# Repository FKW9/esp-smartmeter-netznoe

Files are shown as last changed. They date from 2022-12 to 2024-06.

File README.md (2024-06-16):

# ESP32 Smartmeter Logger für P1 Kundenschnittstelle
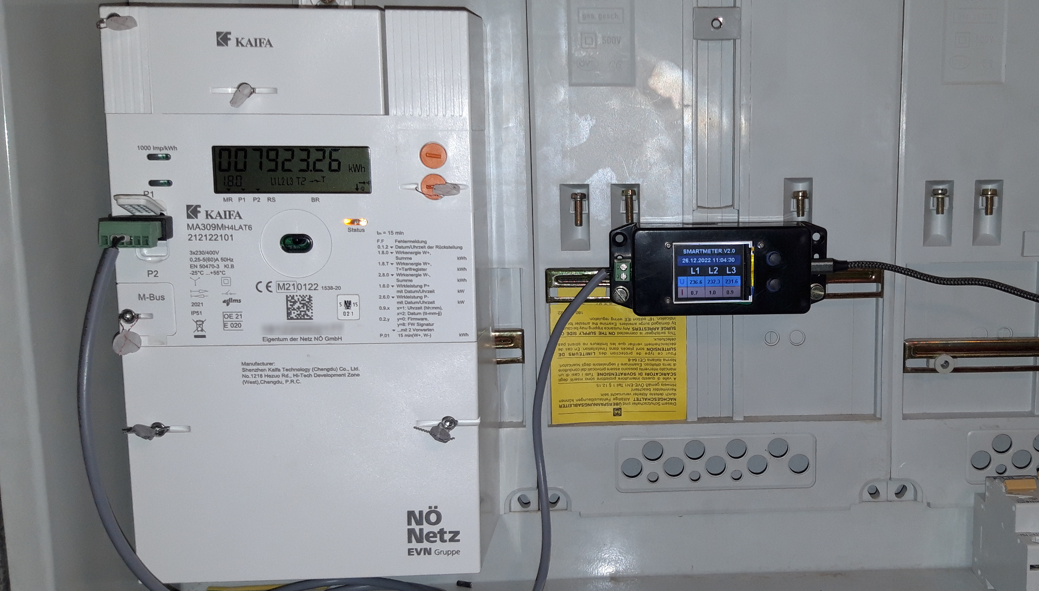
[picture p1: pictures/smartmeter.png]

Musste mich gegen ein DIN-Hutschienengehäuse entscheiden, da in meinem Schaltschrank kein Platz mehr war...

## Quellen
 - DLMS Entschlüsselung: [esphome-dlms-meter](https://github.com/DomiStyle/esphome-dlms-meter)
 - Datenlogger: [ESPLogger](https://github.com/fabianoriccardi/ESPLogger)
 - Fileserver: [esp32-asyncwebserver-fileupload](https://github.com/smford/esp32-asyncwebserver-fileupload-example)
 - weitere siehe [platformio.ini](/platformio.ini)

## Unterstützte Smartmeter
- Kaifa MA309M
- Sagecom T210-D

## Unterstützte (bekannte) Netzbetreiber
- Netz Niederösterreich
- VKW (in Entwicklung, siehe Branch [vkw-test](https://github.com/FKW9/esp-smartmeter-netznoe/tree/vkw-test) und [Issue #10](https://github.com/FKW9/esp-smartmeter-netznoe/issues/10)

## Features
- Lest alle verfügbaren OBIS Daten von der Kundenschnittstelle P1 aus
- Speichert alle Daten auf einer SD-Karte im CSV Format ab
- Daten können über einen Webserver heruntergeladen werden
- Daten können an eine [Graphite-Datenbank](https://graphiteapp.org/) gesendet werden
- On-board [Feuchte und Temperatursensor](https://github.com/epluse/HTE501_i2c_arduino)
- TFT Display auf dem aktuelle Werte zu sehen sind, welches sich automatisch nach 2 Minuten inaktivität ausschaltet.
- [WiFi Manager](https://github.com/tzapu/WiFiManager) zum bequemen Aufsetzen

## Allgemeines
Zunächst muss der Entschlüsselungscode angefordert werden. Für Niederösterreich E-Mail an: [smartmeter@netz-noe.at](mailto:smartmeter@netz-noe.at)

Information zur Kundenschnittstelle (netz-nö) sind hier zu finden: [www.netz-noe.at/SmartMeter_Kundenschnittstelle_lektoriert.aspx](https://www.netz-noe.at/Download-(1)/Smart-Meter/218_9_SmartMeter_Kundenschnittstelle_lektoriert_14.aspx).
## Bekannte Probleme
Leistungsfaktor ist teils unglaubwürdig, siehe dazu [Issue #7](https://github.com/FKW9/esp-smartmeter-netznoe/issues/7)

## Software Installation
Das Projekt wurde in PlatformIO entwickelt. Um es zu kompilieren, bitte Einstellungen in [**```platformio.ini```**](platformio.ini) übernehmen.

[**```key.h```**](key.h):
- ```KEY[]```: Hier **muss** der Entschlüsselungs-Code eingetragen werden

[**```config.h```**](config.h):
- ```SD_CARD_LOGGING```: Speichern auf SD-Karte bzw. den Fileserver (de)aktivieren
- ```USE_GRAPHITE```: Daten an Graphite senden (de)aktivieren

### TFT Display Setup
siehe [**```lib/display/README.md```**](lib/display/README.md)

### Optionale Einstellungen
[**```lib/fileserver/fileserver.h```**](lib/fileserver/fileserver.h):
- ```default_httppassword = "admin"```: Fileserver Login Username
- ```default_httppassword = "smartmeter"```: Fileserver Login Passwort

### Test Setup
In [platformio.ini](/platformio.ini) kann das Flag ```TEST_SETUP``` verwendet werden, um ohne Smartmeter die Funktionalität zu überprüfen. Dazu muss **mein** Schlüssel in [key.h](/key.h) verwendet werden.

## Flowchart
```mermaid
flowchart LR
   Smartmeter -- M-Bus --> a[M-Bus UART Konverter] -- UART --> ESP32
   ESP32 --> Decrypting
   subgraph ESP32
   Decrypting -- save -->b[SD-Karte]
   c[SD-Karte] -- serve --> Webserver
   Decrypting-- push --> d[Graphite Server]
   end
   ESP32-- display -->e[TFT Display]
```

## Hardware
Für eine simplere Hardware Version siehe [Release V0.1](https://github.com/FKW9/esp-smartmeter-netznoe/tree/V0.1).

Als Folge meiner ersten Version wurde hier eine eigene PCB mit mehr Features entworfen.
Diese beinhaltet folgende Kern-Komponenten:
- ESP32-S Modul (mit IPEX Konnektor für Antenne, falls schlechter Empfang)
- CP2102 USB-UART Konverter
- Micro SD-Karten Slot
- 1,77 Zoll TFT Display (160x128px)
- TSS721ADR M-Bus zu UART Konverter (Spende vom [M-Bus Slave Click](https://www.mikroe.com/m-bus-slave-click) Board😉)
- Zweipolige Steckklemme für M-Bus Anschluss (TODO: besser wäre direkt eine RJ12 Buchse!)
- Micro USB für Versorgung bzw. Debugging
- Zwei Taster für die Menüführung

Schaltplan, BOM, Anmerkungen, Zukünftige Verbesserungen der PCB usw. befinden sich im Ordner [hardware](/hardware/).

Für einen "simplen" Aufbau wird folgendes benötigt:
- [M-Bus Slave Click](https://www.mikroe.com/m-bus-slave-click) Board (oder Kompatible)
- ESP32 Development Board, vorzugsweise mit SD-Karten Slot
- RJ12 Kabel bzw. (optional) RJ12 Adapter ([Amazon](https://www.amazon.de/ASHATA-Schraubklemmen-Terminalblock-Schraubanschluss-Konverter-default/dp/B07N3WY7R5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), [AliExpress](https://de.aliexpress.com/item/32870211601.html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)) (Anmerkung: Die Gummiisolierung muss etwas getrimmt werden, damit er passt)
- *(optional)* Micro SD-Karten Modul
- *(optional)* 1,77 Zoll TFT Display ([Amazon](https://www.amazon.de/AZDelivery-TFT-Display-128x160-Pixeln-gratis/dp/B078JBBPXK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), [AliExpress](https://de.aliexpress.com/item/32812455774.html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)) (Anmerkung: Ist derzeit noch voll im Programm integriert und kann nicht einfach "auskommentiert" werden)

### Verbindungen zwischen ESP und M-Bus:
| ESP32-S Modul | | M-Bus Slave Board | RJ12 | Anmerkung |
|---|---|---|---|---|
| 3.3V  | | 3V3 | | Versorgung |
| GND | | GND | | Masse |
| RXD 2 | GPIO16 | TX | | Empfangene Daten vom M-Bus |
| TXD 2 | GPIO17 | RX | | Optional, da wir keine Daten senden |
| | | MBUS1 | 3 | M-Bus Ausgang, Polarität egal |
| | | MBUS2 | 4 | M-Bus Ausgang, Polarität egal |

### Verbindungen zwischen ESP und TFT Display:
| ESP32-S Modul | | TFT Display | Anmerkung |
|---|---|---|---|
| 3.3V  | | VCC | Versorgung |
| GND | | GND | Masse |
| SCK | GPIO18 | SCK | |
| MOSI  | GPIO23 | SDA | |
| MISO  | GPIO19 | RES | |
| | GPIO25 | RS | |
| SS | GPIO5  | CS | |
| | GPIO26 | LEDA | Display an/aus (Hintergrundbeleuchtung) |

### Verbindungen zwischen ESP und TFT Display:
**Achtung:** Ob ein SPI Micro SD-Karten Modul kompatibel mit dem TFT Display ist, weiß ich nicht. Ich verwende die SD-Karte im 4-Bit SD Bus Mode, welcher folgend aufgelistet ist.
| ESP32-S Modul  | SD-Karte | | Anmerkung |
|---|---|---|---|
| 3.3V | VDD | | Versorgung |
| GND | VSS | | Masse |
| GPIO2  | SD_DATA0 | DAT0 | |
| GPIO4  | SD_DATA1 | DAT1 | |
| GPIO12 | SD_DATA2 | DAT2 | |
| GPIO13 | SD_DATA3 | CD/DAT3 | |
| GPIO15 | SD_CMD | CMD | |
| GPIO14 | SD_CLK | CLK | |
| GPIO27 | SD_CD | CD | Card detect. Erkennt, ob SD-Karte physisch vorhanden ist (Schließer). |
---
## Showcase

### **Fileserver**
Für jeden Monat wird eine Datei erstellt. Ein Monat hat ca. 60MB und dauert somit ungefähr 5 Minuten zum Herunterladen.
Als Übersicht wird oben der SD-Karten Status (Freier Speicher, usw.) angezeigt.
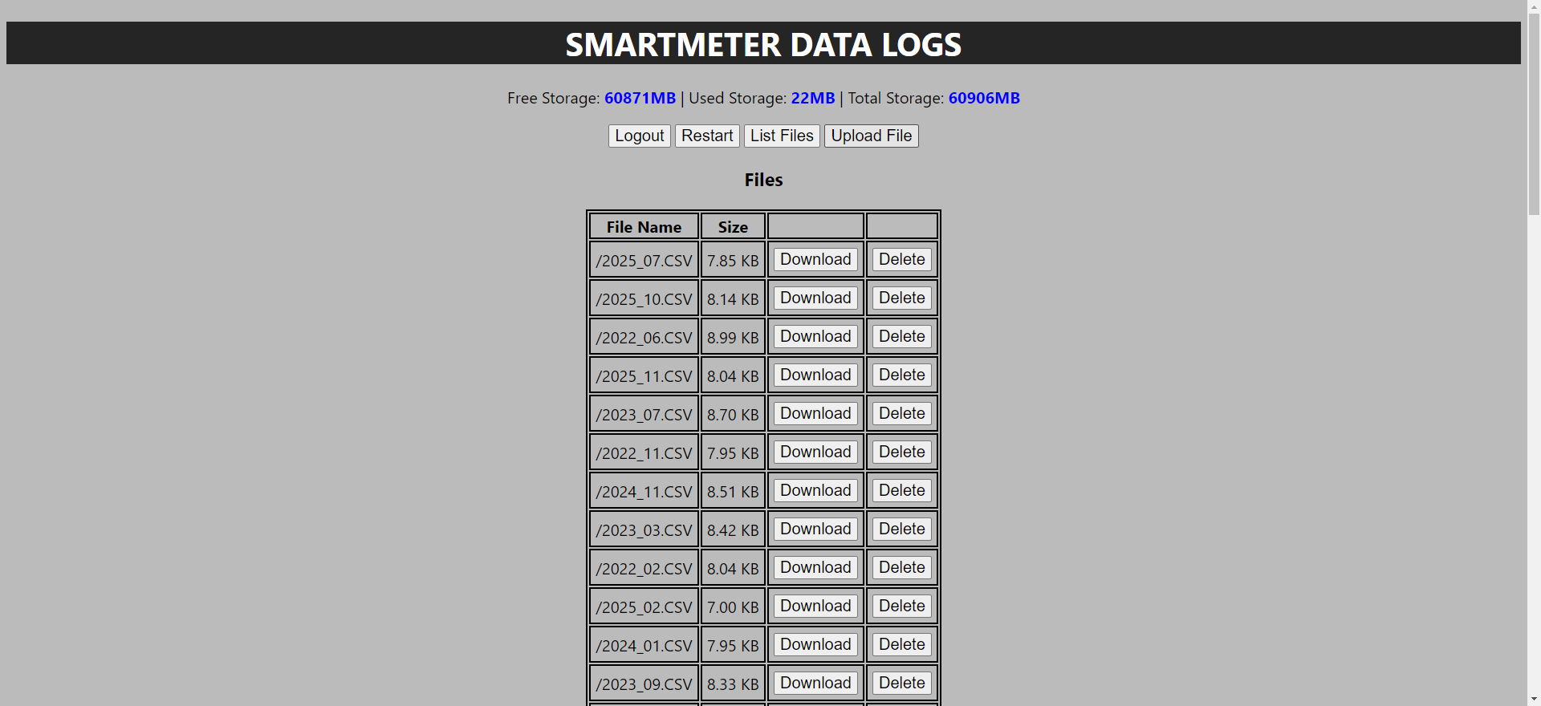
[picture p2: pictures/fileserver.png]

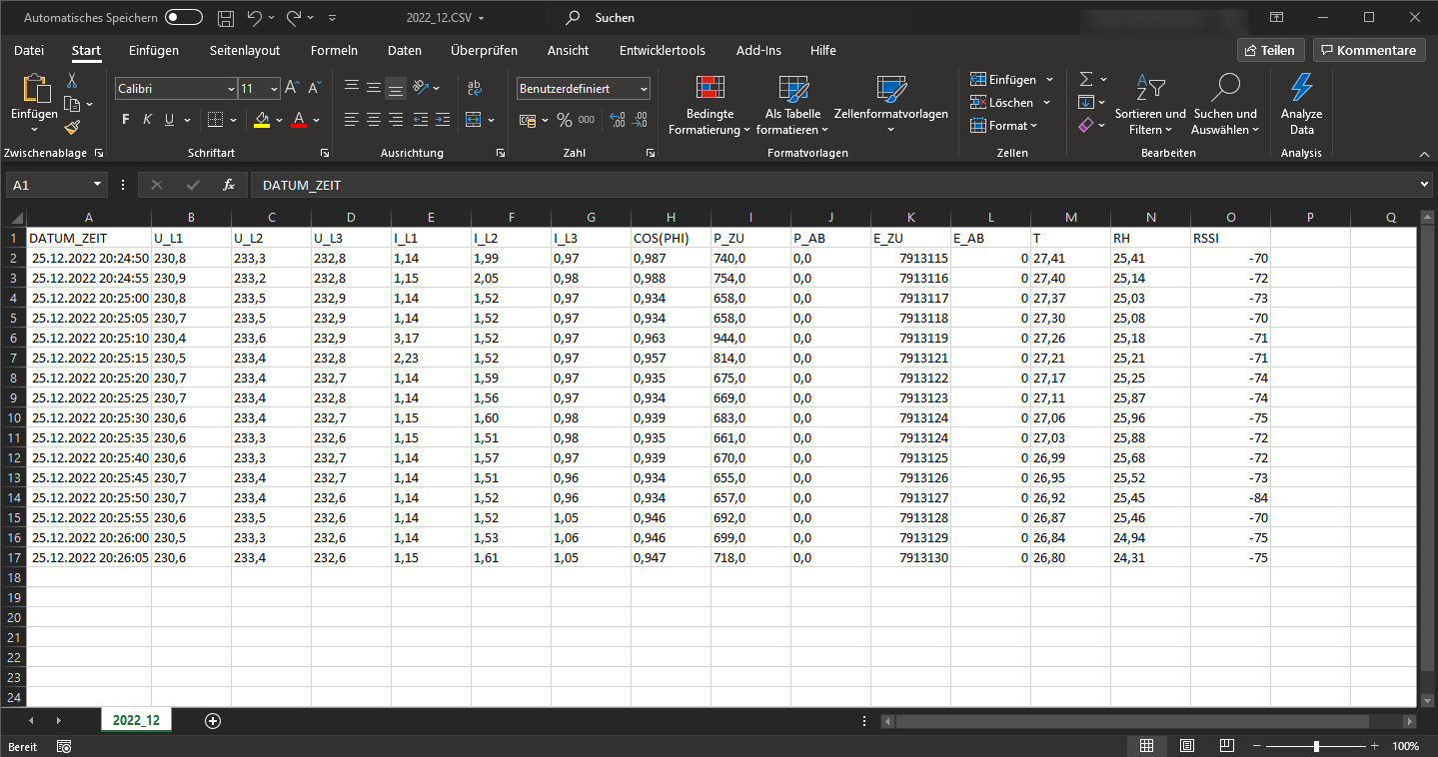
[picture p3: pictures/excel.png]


### **Visualisierung**
Zur Visualisierung wird Grafana (und Graphite) verwendet. Beide Programme laufen auf einem NAS (Synology DS218).
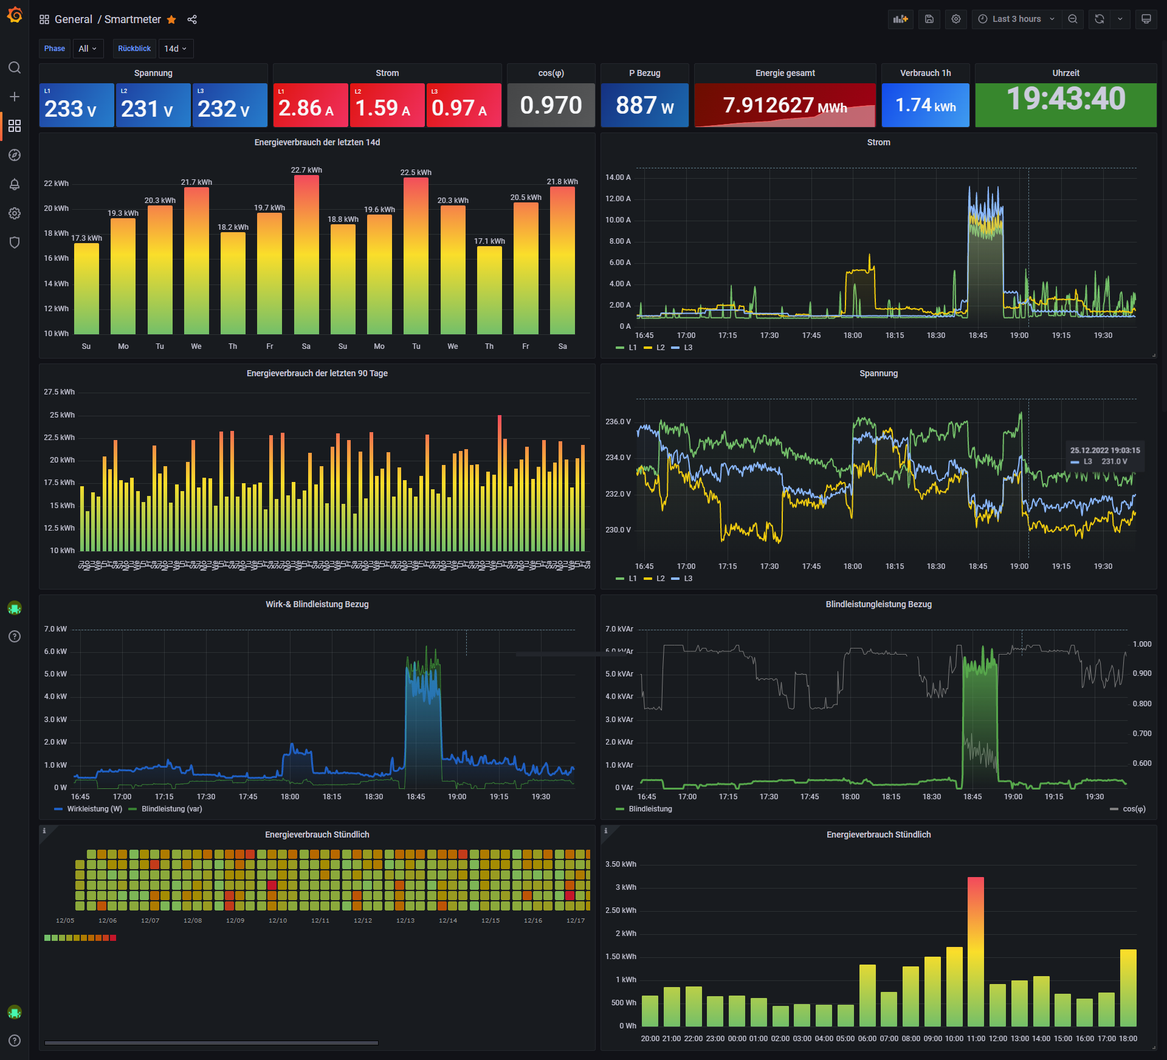
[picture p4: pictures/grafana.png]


### **TFT Display**
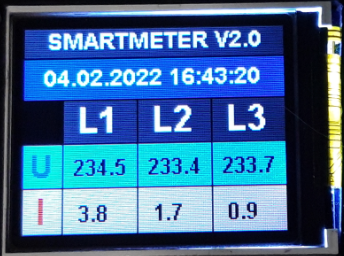
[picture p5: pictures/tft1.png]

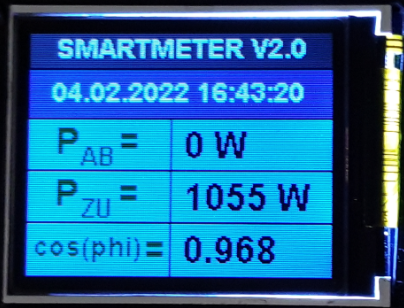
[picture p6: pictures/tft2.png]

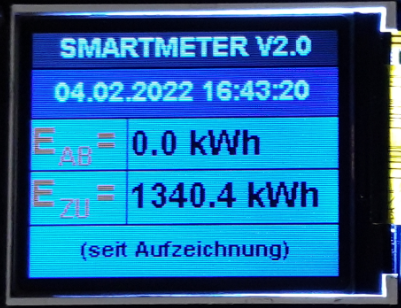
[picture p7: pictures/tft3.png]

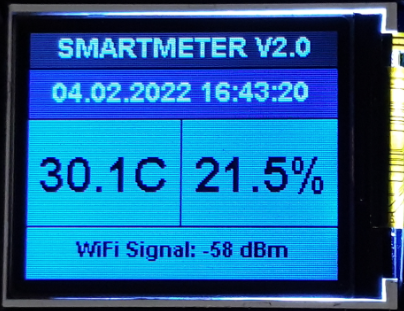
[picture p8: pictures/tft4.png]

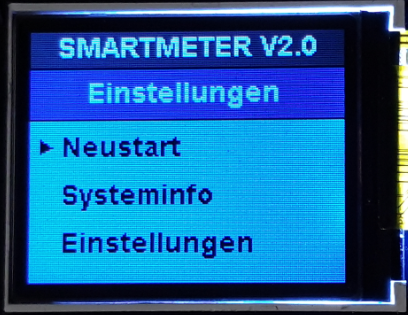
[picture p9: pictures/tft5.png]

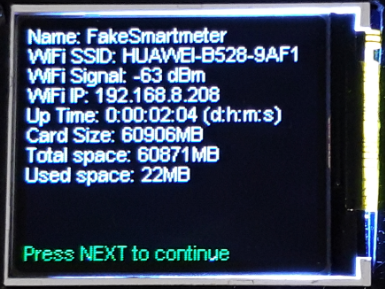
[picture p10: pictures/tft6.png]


### **PCB**
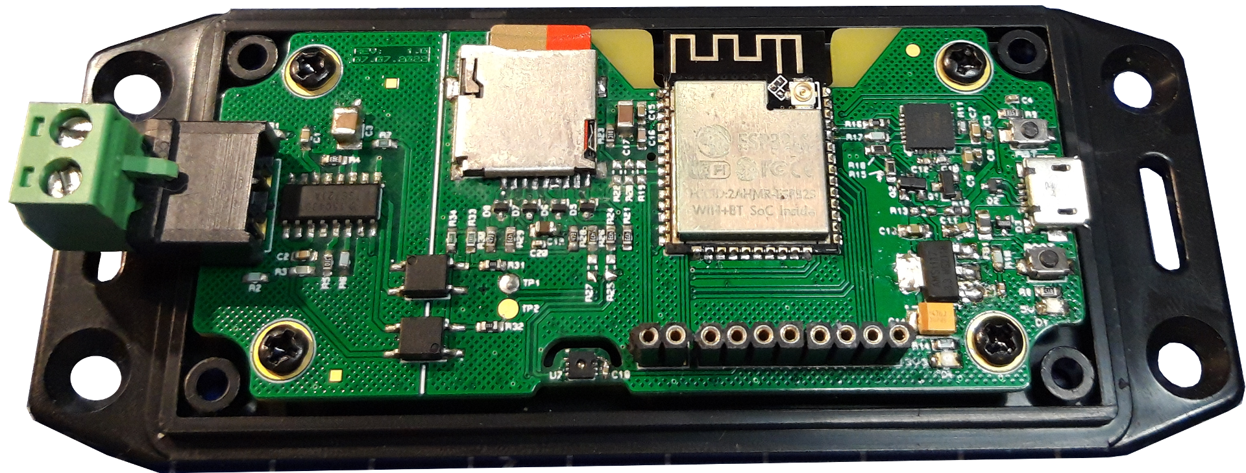
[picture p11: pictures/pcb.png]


## Zukünftiges
Es gibt noch viele Ideen für weitere Entwicklungen, siehe dazu:
- Hardware: [TODO's](/hardware/TODO.md)
- Software: [TODO's](/TODO.md)

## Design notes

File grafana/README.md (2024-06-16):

# Grafana Dashboard

Damit man im Diagramm "Energieverbrauch er letzten 7 Tage" die Wochentage sieht, musste etwas an der Grafana config umgestellt werden. Siehe mein Forum-Beitrag: [https://community.grafana.com/t/default-datetime-formatting-to-weekday-possible/60702](https://community.grafana.com/t/default-datetime-formatting-to-weekday-possible/60702).

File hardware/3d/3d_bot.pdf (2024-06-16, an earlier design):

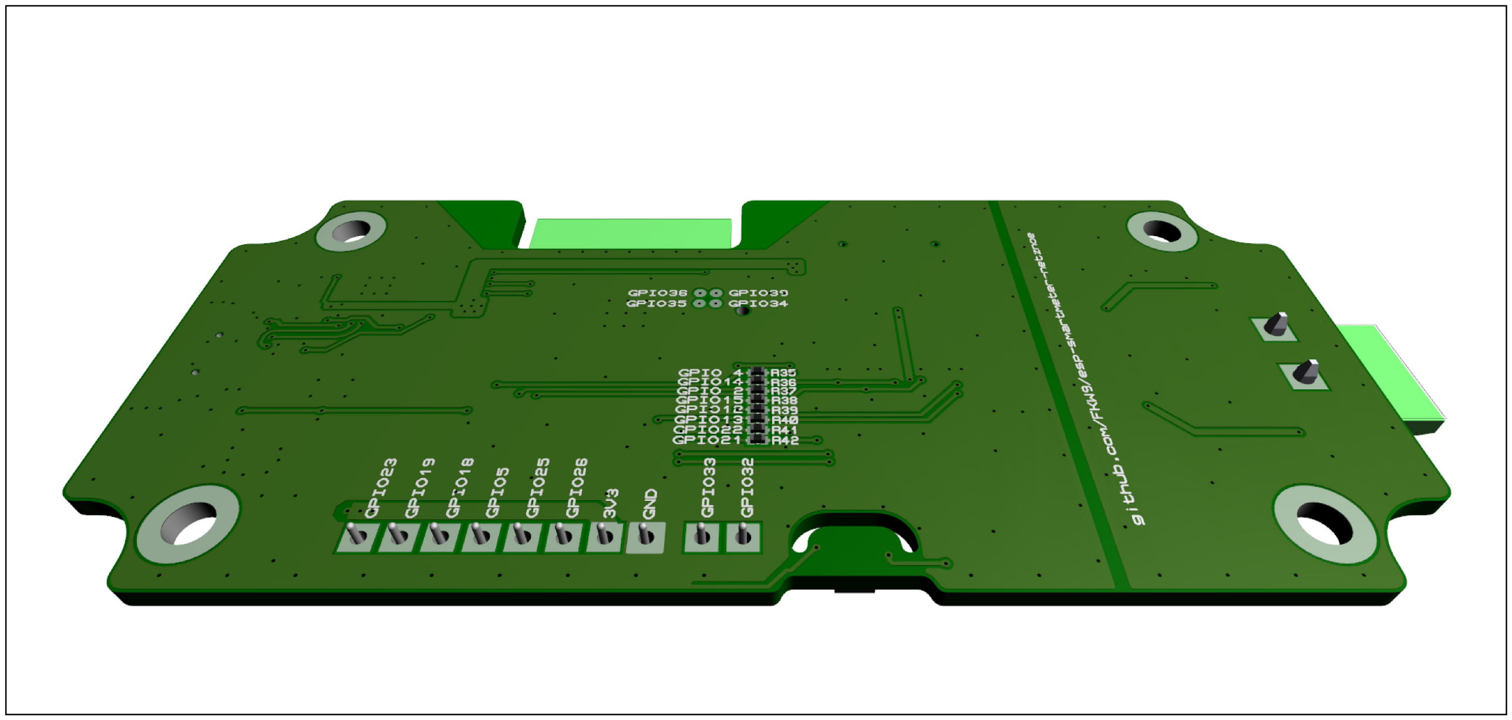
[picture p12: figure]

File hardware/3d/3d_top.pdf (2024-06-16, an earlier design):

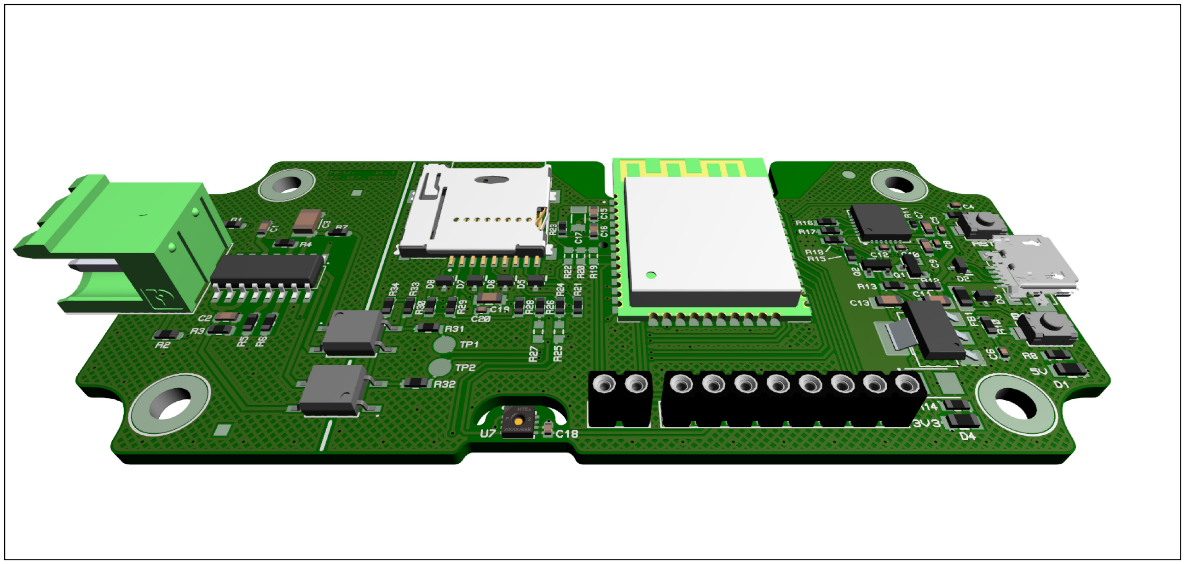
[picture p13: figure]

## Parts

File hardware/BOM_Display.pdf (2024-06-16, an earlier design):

## Bill Of Materials for ESP Smartmeter Logger

Design Title | ESP Smartmeter Logger
Author | FW
Document Number | 0.1
Revision | 1.0
Assembly Variant | STANDARD
Board | Display
Design Created | Sonntag, 12. Juni 2022
Design Last Modified Donnerstag, 16. März 2023

### Total Parts In Design 18

4 Capacitors
Quantity | References | Value | PCB Package | Unit Cost
1 | C1 | 10uF | 1206_CAP | €0,025
1 | C2 | 0.1uF | 0603_CAP | €0,025
2 | C3-C4 | 1uF | 0603_CAP | €0,025
Sub-totals: | | | | €0,100
8 Resistors
Quantity | References | Value | PCB Package | Unit Cost
6 | R1-R6 | 0 | 0603_RES | €0,000
2 | R7-R8 | 10k | 0603_RES | €0,010
Sub-totals: | | | | €0,020
1 Integrated Circuits
Quantity | References | Value | PCB Package | Unit Cost
1 | U1 | TFTDISPLAY | TFT1.77INCH | €3,000
Sub-totals: | | | | €3,000
2 Connectors
Quantity | References | Value | PCB Package | Unit Cost
1 | J1 | CONN-SIL8 | CONN-SIL8 | €0,100
1 | J2 | CONN-SIL2 | CONN-SIL2 | €0,100
Sub-totals: | | | | €0,200
2 Switches
Quantity | References | Value | PCB Package | Unit Cost
1 | SW1 | BUTTON1 | MULTIMEC_3CTH9_10.4 | €1,000
1 | SW2 | BUTTON2 | MULTIMEC_3CTH9_10.4 | €1,000
Sub-totals: | | | | €2,000
1 Additional Cost
Quantity | References | Value | PCB Package | Unit Cost
1 | CT1 | PCB | NULL | €1,000
Sub-totals: | | | | €1,000
Totals: | | | | €6,320

Donnerstag, 16. März 2023 19:24:50

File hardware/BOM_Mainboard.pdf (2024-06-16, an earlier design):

## Bill Of Materials for ESP Smartmeter Logger

Design Title | ESP Smartmeter Logger
Author | FW
Document Number | 0.1
Revision | 1.0
Assembly Variant | STANDARD
Board | Mainboard
Design Created | Sonntag, 12. Juni 2022
Design Last Modified Donnerstag, 16. März 2023

### Total Parts In Design 92

19 Capacitors
Quantity | References | Value | PCB Package | Unit Cost
1 | C1 | 0.22uF | 0603_CAP
1 | C2 | 0.1uF | 0603_CAP
1 | C3 | 22uF | 1210_CAP
2 | C4,C6 | 1nF | 0402_CAP | €0,025
4 | C5,C8,C18,C20 | 0.1uF | 0402_CAP | €0,025
2 | C7,C9 | 4.7uF | 0603_CAP | €0,025
2 | C10,C12 | 47pF | 0402_CAP | €0,025
3 | C11,C13,C19 | 10uF | 0805_CAP | €0,025
1 | C15 | 0.1uF | 0603_CAP | €0,025
1 | C16 | 1uF | 0603_CAP | €0,025
1 | C21 | 10uF | NULL | €0,025
Sub-totals: | | | | €0,400
36 Resistors
Quantity | References | Value | PCB Package | Unit Cost
2 | R1-R2 | 220 | 0603_RES
1 | R3 | 100k | 0603_RES
1 | R4 | 30k | 0603_RES
1 | R5 | 10k | 0603_RES
1 | R6 | 100 | 0603_RES
3 | R7,R33-R34 | 1k5 | 0603_RES
1 | R8 | 3k3 | 0603_RES | €0,010
3 | R9-R10,R17 | 470 | 0603_RES | €0,010
1 | R11 | 2k | 0402_RES | €0,010
4 | R12,R16,R31-R32 | 0 | 0603_RES | €0,010
1 | R14 | 2k | 0603_RES | €0,010
2 | R15,R18 | 12k | 0603_RES | €0,010
6 | R21,R24,R26,R28-R30 | 47k | 0603_RES | €0,010
1 | R23 | 10k | 0603_RES | €0,010
8 | R35-R42 | 0 | 0402_RES | €0,010
Sub-totals: | | | | €0,270
7 Integrated Circuits
Quantity | References | Value | PCB Package | Unit Cost
1 | U1 | TSS721ADR | SOIC127P600X175-16N
2 | U2-U3 | EL357NC-TA-G | EL357NCTAG
1 | U4 | CP2102N | QFN50P500X500X100-29N-D | €3,000
1 | U5 | AMS1117-3V3 | SOT223-4 | €0,300
1 | U6 | ESP-WROOM-32 | ESP32-S | €4,000
1 | U7 | HTE501 | DFN-8 HTE501 | €2,000
Sub-totals: | | | | €9,300
2 Transistors

Quantity | References | Value | PCB Package | Unit Cost
2 | Q1-Q2 | BC846B | SOT23 | €0,080
Sub-totals: | | | | €0,160
8 Diodes
Quantity | References | Value | PCB Package | Unit Cost
2 | D1,D4 | LED | 0805 | €0,100
6 | D2-D3,D5-D8 | NZL5V6AXV3T1G | SOTFL50P160X80-3N | €0,080
Sub-totals: | | | | €0,680
1 Ferrite Beads
Quantity | References | Value | PCB Package | Unit Cost
1 | FB1 | 1k@100MHz | 0805 | €0,200
Sub-totals: | | | | €0,200
5 Connectors
Quantity | References | Value | PCB Package | Unit Cost
1 | J1 | PHOENIX_1759017 | 1759017 | €1,200
1 | J2 | 101181920001LF | AMPHENOL_101181920001LF | €0,400
1 | J3 | CONN-SIL8 | CONN-SIL8 | €0,100
1 | J4 | CONN-SIL2 | CONN-SIL2 | €0,100
1 | J5 | MICRSO SD SLOT | MEM20750014001A | €0,100
Sub-totals: | | | | €1,900
2 Switches
Quantity | References | Value | PCB Package | Unit Cost
1 | SW1 | EN | 2-PIN TACTILE SWITCH | €0,200
1 | SW2 | BOOT | 2-PIN TACTILE SWITCH | €0,200
Sub-totals: | | | | €0,400
6 Miscellaneous
Quantity | References | Value | PCB Package | Unit Cost
6 | TP1-TP6 | TESTPAD | TP_CIRCLE
Sub-totals: | | | | €0,000
6 Additional Cost
Quantity | References | Value | PCB Package | Unit Cost
1 | CT1 | E-Test | NULL | €10,000
1 | CT2 | MIKROE M-Bus Board (inkl. Versand) | NULL | €32,000
1 | CT3 | Bestücken/Löten (ca. 2h) | NULL | €60,000
1 | CT4 | Versand (Österreich) | NULL | €6,900
1 | CT5 | Kabel+RJ12Adapter | NULL | €3,000
1 | CT6 | PCB (ENIG) | NULL | €4,900
Sub-totals: | | | | €116,800
Totals: | | | | €130,110

Donnerstag, 16. März 2023 20:14:38

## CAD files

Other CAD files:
hardware/CAD/enclosure.dwg

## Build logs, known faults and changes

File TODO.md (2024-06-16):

- [ ] Graphen direkt am Webserver darstellen
  - [ ] HTML auf SD Karte hosten, nicht im Flash
- [ ] Entschlüsselungscode über WiFi Manager eintragen, nicht hardcoden
- [ ] Logging über Loki
- [ ] Bessere Code-Strukturierung
- [ ] Logging Daten auf FTP Server schicken
- [ ] ESP Tasks verwenden!!

... u. V. m

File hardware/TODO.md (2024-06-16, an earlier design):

# TODO's for Hardware Version 2 (if ever...)

## Allgemein
- [ ] Besseres (unkompliziertes) Gehäuse
- [ ] Zusätzliche Eingänge für [Strommessspulen](https://www.amazon.de/DollaTek-SCT-013-000-Nichtinvasiver-Wechselstromsensor-Kerntransformator/dp/B07PMGHC95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) für Messung einzelner Abschnitte im Haus
- [ ] Bauteilwahl überdenken
---
## Mainboard
- [ ] ESP32 um 180° Drehen und nach unten setzen, um Strompfad zum AMS1117 möglichst kurz zu machen
- [ ] Verbindung zum Display verbessern
  - FFC? Anders Kabel? Andere Stiftleisten?
- [ ] RJ12 Buchse statt Steckklemme, damit man keinen Adapter braucht
- [ ] Zweite Möglichkeit für Spannungsversorgung
  - Standard DC Power Jack?
- [ ] Größere und mehr Testpads!!
- [ ] RHT Sensor ist nur als "PCB Temperatur" anzusehen -> besser entkoppeln
- [ ] SD Slot und USB weiter nach Außen setzen

...

---
## Display
- [ ] Bessere Befestigung

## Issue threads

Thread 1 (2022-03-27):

[Question] Which GPI Pins are used ?

Noschvie, 2022-03-27:
Hello
how have the M-Bus Interface (RX, TX) to be connected to the ESP-WROOM-32 ?
Want use this device : [ESP32 NodeMCU](https://www.az-delivery.de/en/products/esp32-developmentboard)

https://github.com/mitsubishievo99/esp-smartmeter-netznoe/blob/83cd244952b45712161aca232fa0c840dfb842c4/src/main.cpp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

Thanks!

mitsubishievo99, 2022-03-27:
@Noschvie RX is not used on the M-Bus Slave.

You have to connect **TX** to **GPIO16**

Noschvie, 2022-03-27:
Thanks!

Closed 2022-03-27.

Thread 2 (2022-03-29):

How-To Compile this Project ?

Noschvie, 2022-03-29:
Is there a How-To get this compiled and running ?
Thanks!

mitsubishievo99, 2022-03-29:
Yes, this was a successful build.
Can you upload it to your ESP?
BTW check the selected environment, you built it for ESP8266

Noschvie, 2022-03-29:
Visual Studio Code is running in a virtual machine, recompiled for ESP32.

Using ESP-Flasher-Windows-x64.exe leads to this output:

```
Using 'COM4' as serial port.
Connecting....
Detecting chip type... ESP32
Connecting....

Chip Info:
 - Chip Family: ESP32
 - Chip Model: ESP32-D0WDQ6 (revision 1)
 - Number of Cores: 2
 - Max CPU Frequency: 240MHz
 - Has Bluetooth: YES
 - Has Embedded Flash: NO
 - Has Factory-Calibrated ADC: YES
 - MAC Address: 24:62:AB:FC:B5:C0
Uploading stub...
Running stub...
Stub running...
Changing baud rate to 460800
Changed.
 - Flash Size: 4MB
 - Flash Mode: dio
 - Flash Frequency: 40MHz
Erasing flash (this may take a while)...
Chip erase completed successfully in 7.3s
Flash will be erased from 0x00001000 to 0x00005fff...
Flash will be erased from 0x00008000 to 0x00008fff...
Flash will be erased from 0x0000e000 to 0x0000ffff...
Flash will be erased from 0x00010000 to 0x000d2fff...
Compressed 17104 bytes to 11191...
Writing at 0x00001000... (100 %)
Wrote 17104 bytes (11191 compressed) at 0x00001000 in 0.4 seconds (effective 316.5 kbit/s)...
Hash of data verified.
Compressed 3072 bytes to 129...
Writing at 0x00008000... (100 %)
Wrote 3072 bytes (129 compressed) at 0x00008000 in 0.0 seconds (effective 523.7 kbit/s)...
Hash of data verified.
Compressed 8192 bytes to 47...
Writing at 0x0000e000... (100 %)
Wrote 8192 bytes (47 compressed) at 0x0000e000 in 0.1 seconds (effective 948.9 kbit/s)...
Hash of data verified.
Compressed 794704 bytes to 458939...
Writing at 0x00010000... (3 %)
...
Writing at 0x000d1eb0... (100 %)
Wrote 794704 bytes (458939 compressed) at 0x00010000 in 11.1 seconds (effective 574.0 kbit/s)...
Hash of data verified.

Leaving...
Hard Resetting...
Hard resetting via RTS pin...
Done! Flashing is complete!

Showing logs:
[21:43:06]ets Jun  8 2016 00:22:57
[21:43:06]
[21:43:06]rst:0xc (SW_CPU_RESET),boot:0x13 (SPI_FAST_FLASH_BOOT)
[21:43:06]configsip: 0, SPIWP:0xee
[21:43:06]clk_drv:0x00,q_drv:0x00,d_drv:0x00,cs0_drv:0x00,hd_drv:0x00,wp_drv:0x00
[21:43:06]mode:DIO, clock div:2
[21:43:06]load:0x3fff0018,len:4
[21:43:06]load:0x3fff001c,len:1044
[21:43:06]load:0x40078000,len:10124
[21:43:06]load:0x40080400,len:5828
[21:43:06]entry 0x400806a8

```

mitsubishievo99, 2022-03-29:
Is the last part the serial output of the ESP?
If you get this Message after line "Showing logs" continuously, it seems like you are stuck in a boot loop, but i cannot tell from this log.

Are you receiving messages from the ESP?
You can check this by connecting to the serial port on which your ESP is and restart it and you should see messages appear.

Noschvie, 2022-03-30:
Something is missing to get this firmware running.
Flashing Tasmota to this ESP using ESP-Flasher-Windows-x64.exe leads to a running system.

Have no display connected and tested with disconnected / connected M-Bus interface.
Any idea ?

mitsubishievo99, 2022-03-30:
Sorry, i do not really understand what's your problem.

The warnings seen in [here](https://github.com/mitsubishievo99/esp-smartmeter-netznoe/issues/2#issuecomment-1082310549) can be ignored.
The ESP should print something to the serial port (when booting), with or without the connected hardware. Please check that first.

Noschvie, 2022-03-31:
Fix #3 solved this issue, thanks!

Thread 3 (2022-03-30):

Identifier "strptime" is undefined

Noschvie, 2022-03-30:
What is missing to get "identifier "strptime" is undefined" solved ?

https://github.com/mitsubishievo99/esp-smartmeter-netznoe/blob/32dca8013baaa83d104a01f038344f367fa77a73/src/main.cpp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

mitsubishievo99, 2022-03-30:
Since you already compiled the code successfully (#2), i am assuming its an IDE/linting problem.
strptime should be included with Arduino.h.
You can try including <time.h> or <TimeLib.h> though

Noschvie, 2022-03-30:
strptime() can be found in .platformio\packages\framework-arduinoespressif32\tools\sdk\include\newlib\time.h
but this script isn't included.

Project can be compiled successfully, but it's strange... and the firmware crashed during boot.

mitsubishievo99, 2022-03-30:
The answer to the problem is found [here](https://community.platformio.org/t/identifier-is-undefined-setenv-tzset/16162).
You can fix it by putting the following code after your includes.
`char *_EXFUN(strptime, (const char *__restrict, const char *__restrict, struct tm *__restrict));`
**This only works for ESP32!**

Closed 2022-03-30.

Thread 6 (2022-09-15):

Setup EVN Key

wuliwux, 2022-09-15:
Hi,

maybe i overread it. but how i setup the EVN Key?
The EVN sends me a Key with a length of 32.

the unsigned char KEY[] in the config.h has a length of 16...

How to Convert the EVN key?

I'm confused...

thanks for help!

greets

Traxler94, 2022-09-15:
0x and then every time 2 digits of your key.
For Example: 0x22 0x2A 0xEH ...

FKW9, 2022-09-15:
yes, a key looks like that: 36C66639E48A8CA4D6BC8B282A793BBB
so it is {0x36, 0xC6, 0x66 ...} and so on

wuliwux, 2022-09-15:
oh, no... so simple...

warum schreib ich eigentlich in englisch?
Hier geht es um die EVN... :-)

Vielen dank für die Hilfe!

2 andere fragen hätte ich noch:

- muss der Smart Meter laut evn portal bereits auf kommunikativ sein damit die Kommunikation mit mod-bus funktioniert?
- Hat jemand eine mqtt version auch schon zusammengebastelt?

vielen dank und
liebe grüße

Traxler94, 2022-09-15:
:D ja so viele werden das ned auf Englisch brauchen :D hab eh überlegt ob ich Deutsch oder Englisch schreiben soll.

Ich glaub bei dem Kommunikativ gehts nur um die Cloud, dass du dir das online ansehen kannst.

Ich habs auf Modbus umgeschrieben.
Kannst gerne haben wennst willst, ich muss aber noch meinen Key und meine Netzwerkzugangsdaten umschreiben.

Irgendwie funktioniert bei mir der Power-Factor nicht. Hab mir das aber noch ned genauer angesehen.
Könntest ja dann mal berichten, ob der bei dir funktioniert.
Ich hab nämlich nicht den Kaifa sondern den Sagemcom T210-D, vielleicht is da irgendwas minimal anders.
Sonst geht alles, läuft aber erst 2 Tage bei mir.

FKW9, 2022-09-15:
Modbus wäre mir neu ... ihr meint wohl Meter Bus? ;)
Die "Original" Version von DomiStyle [esphome-dlms-meter](https://github.com/DomiStyle/esphome-dlms-meter) unterstützt denke ich MQTT, hab darin aber keine Erfahrung.

Traxler94, 2022-09-15:
Ah sorry... ich meinte, dass ich es auf MQTT umgeschrieben hab, ned auf Modbus :D

wuliwux, 2022-09-15:
@mod-bus vs meter-bus...
yes, das ist wohl richtig. :D

@mqtt?
aber hallo, ja bitte...
:-)

lg

Traxler94, 2022-09-16:
@wuliwux ich hoffe man darf das hier so anhängen.
Die [https://github.com/Mbed-TLS/mbedtls.git](url) musst du noch herunterladen, bei der mbedtls musst du aber noch das "include" ändern, da ich die lib direkt im Projektordner abgelegt habe.
[EVN_SmartMeter_MQTT.zip](https://github.com/FKW9/esp-smartmeter-netznoe/files/9581786/EVN_SmartMeter_MQTT.zip)

wuliwux, 2022-09-16:
servus,
erstmal vielen dank für die tollen Inputs.
Hab mal FKW9 Version auf mqtt umgebaut und ein wenig refactoring betrieben.

die daten laufen bei mir jetzt mittels mqtt auf iobroker, richtig nette sache... :-)
Momentanleistung (+/-) ist derweilen leider immer 0.

lg

Traxler94, 2022-09-16:
@wuliwux
Welchen Stromzähler hast du? Kaifa oder Sagemcom?
Bekommst du den PowerFaktor?

wuliwux, 2022-09-16:
den kaifa.

Was meinst du mit PowerFaktor?
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

Traxler94, 2022-09-16:
Den cosphi meinte ich.
Ja das Projekt kenn ich, ist aber leider in Python.
Bin im programmieren ned unbedingt Weltmeister sondern eher Hobbybastler mit viel Strg-C Strg-V und viel Hoffnung, dass es funktioniert wie ich das will :D

Sonst bekomm ich eh alle Werte, nur den cosphi nicht, muss ich mir bei gelegenheit mal ansehn warum das so ist. Ich vermute, dass der Kaifa da was anderes ausgibt als der Sagemcom.

Closed 2022-09-15.

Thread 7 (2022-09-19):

Sagemcom T210-D how to fix Power-Factor (cosphi) not working

SebTrax, 2022-09-19:
Hallo,
Der Code funktioniert auch beim Sagemcom T210-D, nur der Power-Factor geht nicht.
Fehlerbehebung:
Der "obis_data_type" vom Power-Factor ist nicht 0x12 sondern 0x10
Ich habe in main.cpp "case DATA_LONG_UNSIGNED2:" hinzugefügt
und im obis.h "#define DATA_LONG_UNSIGNED2 0x10".
Siehe Screenshots:
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

Traxler94, 2022-09-19:
Was ich bis jetzt gesehen habe, zeigt er da tatsächlich nicht das richtige an.
Ich hab mal die EVN angeschrieben, was da los ist, weil in der Anleitung steht er ja drin.
Ich hab mal so um die 3,5kW von 4kW Gesamt mit Motoren verbraucht und der cos(phi) war bei 0,94-0,98 also eher unglaubwürdig.
Es passt auch rechnerisch ned zusammen, wenn ich die Gesamtleistung aus den Spannungen und Strömen mit dem cos(phi) berechne und mit der Gesamtleistung vom Smartmeter vergleiche.

Ich werd das mal die nächsten Tage verfolgen und wenn nicht, muss ich den cos(phi) wieder rechnen.

Funktioniert beim Kaifa der cos(phi)?
Könntest du mir mal eine entschlüsselte Ausgabe vom Kaifa schickn?

FKW9, 2022-09-19:
cos(phi) funktioniert beim Kaifa und wird auch so explizit angegeben. Werte sind auch realistisch und passen mit der Blindleistung zusammen. Schau mal hier [AuswertungDLMS_ADPU.xlsx](https://github.com/FKW9/esp-smartmeter-netznoe/blob/b0da1e34e10639d481323ae69186ec9f7853c321/data/AuswertungDLMS_ADPU.xlsx), da ist eine entschlüsselte Nachricht. Schau auch mal hier den Graphen an [Pictures](https://github.com/FKW9/esp-smartmeter-netznoe/tree/master/pictures).
Hab remote kein Zugriff auf die Daten.. kann ich der erst am Wochenende mehr erzählen

FKW9, 2022-09-24:
Hier mal mein cos(phi) während ein 6kW Motor arbeitet ;)
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

SebTrax, 2022-09-24:
Naja ein cos(phi) von 0,45 kann ja auch ned wirklich stimmen.
Beim Sagemcom ist der cos(phi) ein signed int und geht in + als auch in - richtung, was eigentlich falsch ist.
Und anscheinend wird der gesamte cos(phi) aus den 3 einzelnen zusammengezählt und da es auch mal möglich ist, dass 2 Phasen vom Netz beziehen und 1 Phase einspeist, kommt da dann noch mehr blödsinn raus.
So zumindest meine Vermutung.
Ich habs der EVN schon geschrieben und warte zurzeit auf eine Antwort. Vielleicht werden die mich eines besseren belehren 😆

Das ist mein cos(phi), hab aber die negativen Werte auf positive umgerechnet.
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

SebTrax, 2022-11-28:
Kurzes Update:
Bei mir wurde wegen dem komischen cos(phi) bei Bezug + Einspeisung jetzt der Zähler auch auf einen KAIFA getauscht.
Die Änderung wie oben bereits beschrieben funktioniert trotzdem beim Sagemcom, sollte jedoch auch eingespeist werden, zeigt der cos(phi) falsche Werte an.

Soundrico, 2023-10-12:
ein Hällöle ausm Ländle,
habs auch nachgebaut - coole Arbeit, Jungs!
habe einen Honeywell DM515 Zähler der VKW bekommen (Schauen eigendlich alle gleich aus die Dinger)...
...Mbus angesteckt und läuft...
...bis auf den cos phi - habe den code angepasst lt der obrigen beschreibung...
...cos phi wird immer noch nicht korrekt angezeigt
...hat jemand eine Idee?

SebTrax, 2023-10-12:
Ich hab das Problem noch immer, dass der cos phi durch null geht, wenn auf einer Phase eingespeist und auf einer anderen bezogen wird.
Ist in meinen Augen ein Fehler in den Zählern.
Vermutlich haben die bei Bezug positive Werte und bei Einspeisung negative und zählen die dann eifach zusammen.

Closed 2022-11-28.

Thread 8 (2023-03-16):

Code auf Arduino verwenden

EIKSEU, 2023-03-16:
Hallo,

versuche den Code auf einem Arduino zu verwenden kannst du mir dabei helfen ich hänge beim entschlüsseln.....

Mfg

SebTrax, 2023-03-16:
Wo hängst du genau?
Hast du den Code von netznoe schon erhalten?
Häng mal deinen Code an, dann könnte man vielleicht sehen wo es hakt. (Natürlich ohne deinen privaten Schlüssel)

EIKSEU, 2023-03-16:
`
#include <Crypto.h>
#include <AES.h>
#include <GCM.h>
#include <Arduino.h>
#include "dlms.h"
#include "obis.h"
#include "key.h"

GCM<AES128> *gcmaes128 = 0;

// Variables for DLMS decoding
uint32_t last_read = 0;                      // Timestamp when data was last read
uint16_t receive_buffer_index = 0;           // Current position in the receive buffer
uint8_t receive_buffer[RECEIVE_BUFFER_SIZE]; // Stores the received data

// Function prototypes
uint32_t swap_uint32(uint32_t val);
uint16_t swap_uint16(uint16_t val);
void serial_dump();

// SETUP
void setup()
{
    // Debug port
    Serial.begin(115200);

    // MBus input
    Serial1.begin(2400, SERIAL_8E1);
//    Serial1.txBufferSize(RECEIVE_BUFFER_SIZE);
    gcmaes128 = new GCM<AES128>();
    Serial1.setTimeout(2);
    Serial.print("\nWarte auf Smartmeter Daten...");
    delay(2000);
}

// MAIN LOOP
void loop()
{
  uint32_t current_time = millis();
  // Read while data is available
    while (Serial1.available())
    {
        if (receive_buffer_index >= RECEIVE_BUFFER_SIZE)
        {
            Serial.println("Buffer overflow!");
            receive_buffer_index = 0;
            return;
        }

        receive_buffer[receive_buffer_index++] = Serial1.read();

        last_read = current_time;
    }
      static unsigned long previous_millis = 0;

        Serial.println(receive_buffer_index);

        uint16_t payload_length = 243;
        uint16_t payload_length_msg1 = 228;
        uint16_t payload_length_msg2 = payload_length - payload_length_msg1;

        uint8_t iv[12]; // Initialization vector

        memcpy(&iv[0], &receive_buffer[DLMS_SYST_OFFSET], DLMS_SYST_LENGTH); // Copy system title to IV
        memcpy(&iv[8], &receive_buffer[DLMS_IC_OFFSET], DLMS_IC_LENGTH);     // Copy invocation counter to IV

        uint8_t ciphertext[payload_length];
        memcpy(&ciphertext[0], &receive_buffer[DLMS_HEADER1_LENGTH], payload_length_msg1);
        memcpy(&ciphertext[payload_length_msg1], &receive_buffer[DLMS_HEADER2_OFFSET + DLMS_HEADER2_LENGTH], payload_length_msg2);

        // Start decrypting
        uint8_t plaintext[payload_length];

        gcmaes128->setKey(key, gcmaes128->keySize());
        gcmaes128->setIV(iv, 12);
        gcmaes128->decrypt(plaintext, ciphertext, payload_length);

        // Decode data
        uint16_t current_position = DECODER_START_OFFSET;
        meterData meter_data;

            if (plaintext[current_position + OBIS_TYPE_OFFSET] != DATA_OCTET_STRING)
            {
                Serial.println("Unsupported OBIS header type!");
                receive_buffer_index = 0;
                return;
            }

            uint8_t data_length = plaintext[current_position + OBIS_LENGTH_OFFSET];

            if (data_length != 0x06)
            {
                // read timestamp
                if ((data_length == 0x0C) && (current_position == DECODER_START_OFFSET))
                {
                    uint8_t dateTime[data_length];
                    memcpy(&dateTime[0], &plaintext[current_position + 2], data_length);

                    uint16_t year;
                    uint8_t month, day, hour, minute, second;

                    year = (plaintext[current_position + 2] << 8) + plaintext[current_position + 3];
                    month = plaintext[current_position + 4];
                    day = plaintext[current_position + 5];
                    hour = plaintext[current_position + 7];
                    minute = plaintext[current_position + 8];
                    second = plaintext[current_position + 9];

                    sprintf(meter_data.timestamp_str, "%02u.%02u.%04u %02u:%02u:%02u", day, month, year, hour, minute, second);

                    meter_data.timestamp_unix = -1;

                    // COMMENTED OUT BECAUSE I DONT WANT THE PAIN CONVERSION WITH TIMEZONZES
                    // JUST USE -1 TO USE TIME OF ARRIVAL ON GRAPHITE HOST
                    //
                    // convert to unix timestamp for graphite
                    // struct tm tm;
                    // if (strptime(meter_data.timestamp_str, "%d.%m.%Y %H:%M:%S", &tm) != NULL)
                    // {
                    //// TODO: detect time zone summer time/winter time
                    //     meter_data.timestamp_unix = mktime(&tm) - 7200;
                    //     Serial.print("Unix Time: ");
                    //     Serial.println(meter_data.timestamp_unix);
                    // }
                    // else
                    // {
                    //     Serial.println("Invalid Timestamp");
                    //     receive_buffer_index = 0;
                    //     return;
                    // }

                    Serial.print("Timestamp: ");
                    Serial.println(meter_data.timestamp_str);

                    current_position = 34;
                    data_length = plaintext[current_position + OBIS_LENGTH_OFFSET];
                }
                else if ((data_length == 0x0C) && (current_position > 225))
                {
                    uint8_t meterNumber[data_length];
                    memcpy(&meterNumber[0], &plaintext[current_position + 2], data_length);

                    // THIS IS THE END OF THE PACKET
                  //  break;
                }
                else
                {
                    Serial.println("Unsupported OBIS header length");
                    receive_buffer_index = 0;
                    return;
                }

            uint8_t obis_code[data_length];
            memcpy(&obis_code[0], &plaintext[current_position + OBIS_CODE_OFFSET], data_length); // Copy OBIS code to array

            current_position += data_length + 2; // Advance past code, position and type

            uint8_t obis_data_type = plaintext[current_position];
            current_position++; // Advance past data type

            uint8_t obis_data_length = 0x00;
            uint8_t code_type = TYPE_UNKNOWN;

            if (obis_code[OBIS_A] == 0x01)
            {
                // Compare C and D against code
                if (memcmp(&obis_code[OBIS_C], OBIS_VOLTAGE_L1, 2) == 0)
                {
                    code_type = TYPE_VOLTAGE_L1;
                }
                else if (memcmp(&obis_code[OBIS_C], OBIS_VOLTAGE_L2, 2) == 0)
                {
                    code_type = TYPE_VOLTAGE_L2;
                }
                else if (memcmp(&obis_code[OBIS_C], OBIS_VOLTAGE_L3, 2) == 0)
                {
                    code_type = TYPE_VOLTAGE_L3;
                }
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
EIKSEU, 2023-03-16:
für einen Sagecom macht das einer so:
`

  void decrypt_text(Vector_GCM &vect) {
  GCM<AES128> *gcmaes128 = 0;
  gcmaes128 = new GCM<AES128>();
  gcmaes128->setKey(key, gcmaes128->keySize());
  gcmaes128->setIV(iv, ivsize);
  gcmaes128->decrypt(plaintext, ciphertext, datasize);
  delete gcmaes128;
}

struct Vector_GCM {
  const char *name;
  byte keysize;
  unsigned int datasize;
  byte authsize;
  byte ivsize;
  byte tagsize;
  uint8_t key[16];
  byte plaintext[MAX_PLAINTEXT_LEN];
  byte ciphertext[MAX_PLAINTEXT_LEN];
  byte authdata[17];
  byte iv[12];
  byte tag[12];
};

IncommingData aktuelleDaten;

Vector_GCM datenMbus = {   //static
  .name        = "AES-128 GCM",
  .keysize     = 16,
  .datasize    = 297,
  .authsize    = 17,
  .ivsize      = 12,
  .tagsize     = 12,
  .key         = { key},
  .plaintext   = {},
  .ciphertext  = {},
  .authdata    = {},
  .iv          = {},
  .tag         = {},
};`

EIKSEU, 2023-03-16:
aber was davon wird für n Kaifa benötigt?

EIKSEU, 2023-03-16:
läuft das bei dir auf einem Arduino?

Noschvie, 2023-03-16:
@EIKSEU Warum verwendest du keinen ESP32? Welches M-Bus Interface hast du zur Verfügung?

SebTrax, 2023-03-16:
Bei mir läufts auf einem ESP32, weil ich für MQTT W-Lan benötige.
Aber fürn Arduino ist der Code eigentlich genau der gleiche. Nur halt ohne die ganzen W-Lan sachen.

Bekommst du überhaupt Daten vom Zähler oder bekommst du gar nix rein?

EIKSEU, 2023-03-16:
da ich arduino sonst auch verwende. Ja es kommen daten der Fehler ist dieser

.....................smartmeter-netznoe.ino:78: undefined reference to `mbedtls_gcm_init'

.......................smartmeter-netznoe.ino:79: undefined reference to `mbedtls_gcm_setkey'

......................smartmeter-netznoe.ino:80: undefined reference to `mbedtls_gcm_auth_decrypt'

......................smartmeter-netznoe.ino:81: undefined reference to `mbedtls_gcm_free'

collect2.exe: error: ld returned 1 exit status

exit status 1

ich habe alle ordner im im Ordner mit der .ino datei kopiert das Problem habe ich von Anfang an daher habe ich es anders versucht

SebTrax, 2023-03-16:
Hast du die mbedtls Library was ich oben verlinkt habe im Projektordner?
Die ist hier nämlich nicht dabei.

EIKSEU, 2023-03-16:
https://github.com/wolfeidau/mbedtls die meinst du?

SebTrax, 2023-03-16:
Ich hab grad nachgesehen.
Ich hab die ganzen Dateien vom Ordner Source auch in den Ordner mbedtls kopiert.

EIKSEU, 2023-03-16:
ok das hab ich jetzt auch aber noch kein erfolg....

EIKSEU, 2023-03-16:
ich habs nun so eingefügt

#include <Arduino.h>
#include "dlms.h"
#include "obis.h"
#include "key.h"
#include "source/mbedtls/gcm.h"
#include "source/gcm.c"

jetzt ist noch dieser fehler ....
\source\gcm.c:82:33: error: invalid conversion from 'void*' to 'volatile unsigned char*' [-fpermissive]
     volatile unsigned char *p = v; while( n-- ) *p++ = 0

hast eine Idee

`You need to cast as you can not convert a void* to anything without casting it first.

You would need to do

unsigned char* etherhead = (unsigned char*)buffer;
(although you could use a static_cast also)

To learn more about void pointers, take a look at [6.13 — Void pointers](http://www.learncpp.com/cpp-tutorial/613-void-pointers/`

das habe ich versucht da sind noch mehr Fehler gekommen

SebTrax, 2023-03-16:
gcm.c musst u nicht einbinden.
Wie hast du denn die Ordner in deinem Projekt angelegt?
liegt der mbedtls ordner im source ordner?
Versuch mal so:
Dein Projekt => mbedtls => hier alle Dateien vom ordner mbedtls und source

Den source Ordner kannst dann löschen und mit
`#include "mbedtls/gcm.h"`
einbinden

EIKSEU, 2023-03-16:
Das hatte ich aber dan passen die includes nicht mehr und die .c datein werden anscheinend nur gefunden wenn ich sie miteinander....

SebTrax, 2023-03-16:
Ich hab grad versucht es für Arduino ohne WiFi zu kompilieren, aber da fehlen dann einen haufen Librarys.
Ich würd sagen, am einfachsten wäre es, wenn du dir einfach einen ESP32 kaufst.
Die kosten ja ned wirklich was und du kannst dann auch mal was mit WLan programmieren, dass du dir z.B. die Werte am Handy ansehen kannst.

EIKSEU, 2023-03-16:
Ok danke für deine Hilfe werde noch versuchen es zu lösen.....

FKW9, 2023-03-16:
Wie SebTrax schon gesagt hat, fehlen viele Librarys für Arduino, unter anderem basiert der ganze WiFi Stack, die TFT-Lib, der Logger, das Filesystem, die GPIOs usw. alles auf dem ESP32.
Am einfachsten wäre es, wenn du ein [ESP32 Devkit](https://www.az-delivery.de/en/products/esp-32-dev-kit-c-v4) für 14€ (auf AliExpress noch billiger) kaufst.
Wenn du bei Arduino bleiben willst, wäre es besser wenn du den Code von Null-auf neu schreiben würdest, mit meinem z.B. als Vorlage. Somit kannst du immer stückweise testen, ob auch alles funktioniert.

Closed 2023-03-17.

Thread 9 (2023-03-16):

[Question] PCB's noch verfügbar ?

Noschvie, 2023-03-16:
Hallo Florian
hättest du noch ein PCB zum Weitergeben ?
mfg
Norbert

FKW9, 2023-03-16:
Hallo, ja, ist noch verfügbar. Brauchst du nur die PCB?

Noschvie, 2023-03-16:
Bestückt wäre noch besser

FKW9, 2023-03-16:
Bestückt und getestet wirds aufjedenfall teurer, weil ich dummerweise keine SMT Schablone habe und die Lötpaste händisch aufbringen muss.

Habe mal die Kosten durchgerechnet (siehe auch in der BOM im Ordner [hardware](https://github.com/FKW9/esp-smartmeter-netznoe/tree/master/hardware)), wenn du alles so ziemlich fertig haben willst.

| **Kostenstelle**                                 | **Preis**     |
|--------------------------------------------------|---------------|
| Mainboard PCB + Bauteile (exkl. M-Bus Konverter) | 18,21€        |
| Display PCB + Bauteile                           | 6,32€         |
| Mikroe M-Bus Konverter (inkl. Versand)           | 32,00€        |
| Bestücken und Löten (ca. 2h) + E-Test            | 70,00€        |
| Kabel + RJ12 Adapter                             | 3,00€         |
| Versand ca. (innerhalb Österreich)               | 6,90€         |
| **_GESAMT_**                                     | **_136,43€_** |

Muss morgen schauen, ob ich noch ein Gehäuse habe ([Hier der Link](https://at.rs-online.com/web/p/universalgehause/3822106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)). Wenn ja, kann ich das noch anbieten (ca. 1h Aufwand).

Noschvie, 2023-03-26:
Suche eine einfachere Lösung, danke nochmals.

Closed 2023-03-26.

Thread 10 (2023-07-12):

VKW - Invalide Daten

da-winci, 2023-07-12:
Bekomme leider nur invalide Daten.
Mir scheint die Länge ist zu kurz, kann das sein?
Was kann ich machen um dem Problem auf die Schliche zu kommen?
Kann ich diese Datenwurst irgendwie händisch oder mit einem Tool entschlüsseln?
Den Entschlüsselungskey habe ich heute bekommen.
Bin wirklich um jede Hilfe dankbar!
Habe einen VKW MA309MH4 Smartmeter.

Laut Code müsste es hier fehlschlagen:
```
if (plaintext[0] != 0x0F || plaintext[5] != 0x0C)
{
     Serial.println("Packet was decrypted but data is invalid!");
     receive_buffer_index = 0;
     return;
}
```

14:26:17.366 -> 68FAFA6853FF000167DB084B464D1020043BD78201552100004483B42D5539F7DC88C9573AFB79C56C3C7A9D86BC3E5845A99FAE35C4CC93EB3247939D73D7EF31DF33BC169026B14B0B0F83225B18E5FC455CDCBB165AB649532E33869A74159289480BFF892769D8BF6C1279CF35CA04839A4A6387374B7610F5AFD57065D0CCF9FEAF2D61AF52AD08F314E20559283E102CB78043275B83A3439B6274F85FD3733768125DADF33D45B27AE6C98E521FE65B5CAFB8BF1BDBF6A478DEB7AC7D5D944C8382E10164FB0BD8B6AB86D9E1A9D22A7EDC3C2FBB8F625E654F322A932FA8CDA73DD0E0B687203A8799A8EC827DF50B685439452B8BDDF019D8202316 Packet was decrypted but data is invalid!
14:26:25.287 -> 68FAFA6853FF000167DB084B464D1020043BD78201552100004484BBF8DFACEF4578719FE6319FEC5F7DED2211FF8136E109033C4E83109DD974A4BABF3F47F66647C46FAC4E721C05DAEA46E714B6E1581FD9994857DE98B694D422C5CADC99D459483D72CF752BAD155D5C6F1C489ADD1F57FDC61901FA70A161DC0C2E8055796631B6C64586B264041078BF856EA3ABE9FCE6F80F29B77DFB4A9FB29A76BF8EDB0CA334D78EF3FBB7FFEE5BC118D3CA04316733DF41CB4561F91B6FAA5BDFD8CBC007A54FFFB918278F8FA122334607D080D012CB898A66806C6DF8C7D47DEEAB9A0CE51C5FAE168042EAB628D90ECD4B0133C0F57384A2C37A2333832B16 Packet was decrypted but data is invalid!
14:26:31.320 -> 68FAFA6853FF000167DB084B464D1020043BD78201552100004486AAC97CCE1C3291DEB08ECAA2AE8E71E87387F96A31C5CB231070E0BBF20FACD1C6BDC727ACF2DF0BCF66CFFB6DD407C22C51706864705CD409C6157024D1639BCFA78257F7BA34AB1DC9C5970A1608D4DAB7953AE8DD1516E2B1993C5D16047071AC6B8DC66FEF4E5DE1AB09EB04263FCAC700BA70BBF206153AC677B8841918B8302F26EC4F559B2F31A133D3E763196E68204F0AB6025A76DA8F1EFFF8DB2AB97B59F0A2415F9CBD34C9F56A464334B249AA710FC9857DD0AC564CC1415CFC7327FB8BB65F88278AB54AF6DFD5C84FCDDB8D8AA393444B6F9D88026C6C05A2FABCB6A116 Packet was decrypted but data is invalid!

Noschvie, 2023-07-12:
VKW ist anders als Netz-NOE, kenne aber leider nicht die Details...

FKW9, 2023-07-12:
Hab mein Python test script hochgeladen
[https://github.com/FKW9/esp-smartmeter-netznoe/tree/0446ace9308a83485453d2600443c40becfa098b/python](https://github.com/FKW9/esp-smartmeter-netznoe/tree/0446ace9308a83485453d2600443c40becfa098b/python)

Bei deinen Daten fehlt das zweite Frame(beginnend mit 68141468). Probier mal das READ_TIMEOUT zu erhöhen.
Hast du einen TTL-USB Adapter? Das wäre optimal um die Daten abzufangen

da-winci, 2023-07-13:
Das READ_TIMEOUT zu erhöhen hatte keine Auswirkung.
Hab nun ein zwei Datenframes mit einem TTL-USB Adapter aufgenommen.
Ich hoffe du kannst daraus mehr rauslesen als ich :)

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

Noschvie, 2023-07-13:
Habe in Erinnerung, dass es jemand mit Tasmota geschafft hat, einen "vorarlbergnetz smartmeter" auszulesen.

micronano0, 2023-07-13:
@da-winci :  ich habe mir deine Datenstream.txt Datei angeschaut und kann im 1. Moment keinen Fehler darin finden.  Die Datensätze sind von der Byteanzahl her gleich lang wie mein Vergleichsdatensatz der funktioniert.
Auch im Header (die 1. 27 Bytes) scheinen korrekt zu sein. Auch das 2. Telegramm (ab Byte 256 ...)  im Datensatz schaut gut aus.

Vielleicht möchtest du deine Daten mit dem Online Tool [CyberChef ](https://gchq.github.io/CyberChef/#recipe=AES_Encrypt(%7B'option':'Hex','string':''%7D,%7B'option':'Hex','string':''%7D,'GCM','Hex','Hex',%7B'option':'Hex','string':''%7D))checken.

AES ENCRYPT:
Key: dein key
IV (12 Bytes): 4B bis  D7 und 00 00 8F A5
Mode: GCM
Input: Hex
Output: Hex

Input:  hier kommt Telegramm1 + Telegramm2 rein

Telegramm1 Beginn: 83 (also BytePos 28 - wenn ich mit 1 zu zählen beginne)
Telegramm1 Ende: 89  (also BytePos 254 - wenn ich mit 1 zu zählen beginne)
Telegramm2 Beginn: A9 (also BytePos 266 - wenn ich mit 1 zu zählen beginne)
Telegramm2 Ende: F3  (also BytePos 374 - wenn ich mit 1 zu zählen beginne)

cyberChef
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

Spalte E = dein Datensatz // Spalte F = mein Datensatz
IV = Zeile 12 bis Zeile 19 und Zeile 24 bis Zeile 27
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

Telegramm1 Ende ... Telegramm2 Start
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

Telegramm2 Ende
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

Im cyberChef siehst du in Output, wenn alles korrekt dekodiert werden konnte, in Hex den OBIS Block.
Wenn du bei AES Encrypt den Output auf "RAW" stellst, dann kannst du zB. die Kaifa Serial Nummer lesen und siehst die Obis Blöcke.

Ich hoffe das hilft für's erste ;-)

FKW9, 2023-07-13:
Also bei VKW beginnt das zweite Frame mit `68 72 72 68`, und die Frames kürzer.
Aufjedenfall danke für deinen fundierten post! @micronano0

da-winci, 2023-07-14:
@micronano0 Mega lieben Dank für deinen wirklich hilfreichen Post!
Mit deinen Vorgaben konnte ich nun folgenden HEX Output generieren.
0f00008eb20c07e7070d04110b1e00ff8880021009060000010000ff090c07e7070d04110b1e00ff8880020209060000600100ff090e314b464d303230303237373436330202090600002a0000ff09104b464d31323030323030323737343633020309060100200700ff12097102020fff1623020309060100340700ff12095702020fff1623020309060100480700ff12095f02020fff16230203090601001f0700ff12013902020ffe1621020309060100330700ff12015702020ffe1621020309060100470700ff12015a02020ffe1621020309060100010700ff060000000002020f00161b020309060100020700ff060000094c02020f00161b020309060100010800ff06000028b602020f00161e020309060100020800ff0600029bf002020f00161e020309060100030800ff06000002e902020f001620020309060100040800ff0600001f0202020f001620

Kannst du damit die richtigen OBIS Blöcke erzeugen und mal schauen ob die generell eigentlich passen?
Wenn ich den Output auf "Raw" einstelle, wird tatsächlich die richtige Smartmeter-Seriennummer angezeigt :)
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

[https://tinyurl.com/DLMSVKW](https://tinyurl.com/DLMSVKW) (Werde diesen Link demnächst löschen wegen Key)

Das zweite Frame der VKW Zähler scheint wohl tatsächlich mit `68 72 72 68` zu beginnen.
Wirklich mega wir kommen der Sache hier gemeinsam näher 👍

@FKW9 Darf ich so frech sein und fragen ob du mir evtl. eine Testversion zur Verfügung stellen könntest, mit angepasstem zweiten Datenframe damit ich das mal testen kann?

FKW9, 2023-07-14:
Datum Zeit:                      13.07.2023 17:11:15
0.0.96.1.0.255  Zaehlernummer:                   1KFM0200277463
0.0.42.0.0.255  COSEM logical device name:       KFM1200200277463
1.0.32.7.0.255  Spannung L1 (V):                 241.1
1.0.52.7.0.255  Spannung L2 (V):                 240.5
1.0.72.7.0.255  Spannung L3 (V):                 239.9
1.0.31.7.0.255  Strom L1 (A):                    3.13
1.0.51.7.0.255  Strom L2 (A):                    3.42
1.0.71.7.0.255  Strom L3 (A):                    3.44
1.0.1.7.0.255   Wirkleistung Bezug [kW]:         0.0
1.0.2.7.0.255   Wirkleistung Lieferung [kW]:     2.376
1.0.1.8.0.255   Wirkenergie Bezug [kWh]:         10.422
1.0.2.8.0.255   Wirkenergie Lieferung [kWh]:     170.982
1.0.3.8.0.255   Blindleistung Bezug [kW]:        0.745
1.0.4.8.0.255   Blindleistung Lieferung [kW]:    7.938

FKW9, 2023-07-14:
Mit drei kleinen Änderungen im Code _sollte_ es funktionieren, wenn ich nichts übersehen habe (Ob der Timestamp funktioniert, bin ich mir nicht sicher):

Hier den Wert auf `27` ändern:
https://github.com/FKW9/esp-smartmeter-netznoe/blob/0446ace9308a83485453d2600443c40becfa098b/src/dlms.h#L7

Und hier die `payload_length` auf `336` und `payload_length_msg1` auf `227` setzen:

https://github.com/FKW9/esp-smartmeter-netznoe/blob/0446ace9308a83485453d2600443c40becfa098b/src/main.cpp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

da-winci, 2023-07-14:
@FKW9 Danke für den schnellen Code Änderungsvorschlag.
Es schlägt noch hier fehl. Muss ich hier auch was ändern bezüglich 0x0F und 0x0C?

`
if (plaintext[0] != 0x0F || plaintext[5] != 0x0C)
{
      Serial.println("Packet was decrypted but data is invalid!");
      receive_buffer_index = 0;
      return;
}
`

FKW9, 2023-07-14:
Nein an diesen Byte-Positionen im Plaintext muss genau das stehen.
Bei den Daten fehlt das 2. Frame ... da gibts irgendwo noch ein Problem

da-winci, 2023-07-14:
Hmm dann verhält sich das mit dem ESP32 über die Serielle schnittstelle noch etwas anders als über den USB-TTL Wandler.

FKW9, 2023-07-14:
Meine Vermutung ist, dass dein 2. Frame mit einer etwas zu großen Verzögerung kommt. Kannst du checken, wie die Daten überm TTL-USB Wandler kommen? Kommt da alles auf einmal oder ist da ein delay dazwischen?

FKW9, 2023-07-14:
Ja mein Fehler, deswegen gibt es ja das READ_TIMEOUT.......

FKW9, 2023-07-14:
Versuch mal dort wo er die Daten ausliest, die einzelnen Bytes direkt zu printen
https://github.com/FKW9/esp-smartmeter-netznoe/blob/8245f22fa37efd4507d7dfbba5b8d040237ec3d1/src/main.cpp#L113

da-winci, 2023-07-14:
Hab nun folgendes in der while(Serial2.available()) schleife eingebaut:
Serial.println(receive_buffer[receive_buffer_index],HEX);
Die Daten scheinen teilweise beim ESP32 aufjedenfall anders interpretiert zu werden als über den USB-TTL Adapter.
[Datenlogging.txt](https://github.com/FKW9/esp-smartmeter-netznoe/files/12050248/Datenlogging.txt)

FKW9, 2023-07-14:
Ja die "rohen" Daten schauen ok aus, man sieht sogar das 2. Frame mit 68727268. Also wirds in meinem Code noch ein Problem geben
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
FKW9, 2023-07-17:
Timestamp wird jetzt im neusten Commit https://github.com/FKW9/esp-smartmeter-netznoe/commit/b2c20f459761682da1d9b9684755af54f8c2330c ausgewertet, zusätzlich  mit epoch time die die Zeitzone berücksichtigt.

In deinem Code verwendest du noch `ACTIVE_ENERGY_PLUS_OFFSET`; das kannst du löschen wenn die es nicht brauchst

laimermic, 2023-07-17:
Seltsamerweise bekomme ich nur invalide Daten. Ich habe es dann mal mit dem TEST_SETUP-flag ausprobiert aber selbst dort bekomme ich nur die Meldung:

`Packet was decrypted but data is invalid!`

und folgenden Encoded raw data stream:

`68FAFA6853FF000167DB084B464D1020043BD78201552100008FA2DF4E42850F1A76EB5A935E4236EA7D26107644C7C163229F2538BEF9E354016C5DFC2DAC071DD083FDD2AB1EB4F335F33FBCE54A88B5C97A529E979B614290FDB2B5DF760A4E88D6984EF23D79C48336D16F299FC3BF16C8072FCCA23EE667C8031757DBFC1FF24EE6738465C90E675D90611BA740CE9125A0300853C0F0D95828E043B50184AAA43FF8335BCE02D6E8A7B5F7818923FBFE30AAC3F619F8B4AF778DAC38BFB3CCFFC59C2231E90E067C5911DC935320E655C2CF1C04CA3805EBED05163904138F2BE3C7FDE84F7FCEAC9519F99D3343BD64FCB110BAD698BF67AE112EB4166872726853FF110167355183CB78C9E3C40670CC906A45E6133862A3847E453A5BC811D3803D98C1C47E161FB0F1C7478E65AB29A51F790AC0AF685B136E37B4A9E7FA10C27DB29E4E29B84A8603120FEB4DFC4EF587F6B3E8148E4570FA99BA97B3C941A097A79D3558102C249ACBEF12561AA58EF2E416`

Mache ich irgendetwas falsch?

Ich verwende den bereits in der key.h-Datei vorhandenen Schlüssel:
```c++
// Your Encryption Key
static const unsigned char KEY[] = {0x35, 0x32, 0x36, 0x32, 0x34, 0x34, 0x34, 0x35, 0x37, 0x36, 0x34, 0x36, 0x34, 0x32, 0x34, 0x34, 0x35, 0x37, 0x37, 0x31, 0x33, 0x36, 0x36, 0x36, 0x33, 0x39, 0x36, 0x43, 0x35, 0x32, 0x35, 0x37};
```

FKW9, 2023-07-17:
Der key ist falsch, da würde der key von @da-winci hingehören, aber den habe ich natürlich nicht veröffentlicht.
Wie sehen deine Daten aus? Ist das zweite Paket da, beginnend mit `68727268` (VKW)? Enden deine Pakete mit `16`?

micronano0, 2023-07-17:
@laimermic
Hallo Michael, möchtest du mal im [Arduino Simulator](https://wokwi.com/projects/370340623912694785) ausprobieren, ob du Daten bekommst?
Du mußt "nur" in Zeile 25  deine Raw Daten vom Zähler hineingeben (rxBuffer ....).
Der key wird beim Programmstart abgefragt. Er ist ohne die 0x einzugeben. Einfach deinen 32stelligen key reinkopieren und Enter

laimermic, 2023-07-18:
Wies aussieht hab ich es einfach nur nicht hinbekommen meinen Key in key.h richtig einzusetzen. Trotzdem danke 👍

Closed 2023-07-18.

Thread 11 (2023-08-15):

Testdaten

HWHardsoft, 2023-08-15:
Hallo,

Ich habe Deinen Code etwas vereinfacht (Display und Wifi entfernt) und mit  der Arduino IDE erfolgreich kompiliert. Ich möchte diesen Code als Beispielcode für die Einbindung von Stromzählern für einen eigenen MBUS Slave Feather Wing verwenden.

Leider komme ich aus Deutschland und bei uns sind die Stromzähler mit RS485 ausgestattet. Deshalb meine Frage. Gibt es irgndwo Testdaten (mit dem dazugehörigen Key) mit denen man die Software testen kann? Oder gar einen Simulator für den Zähler?

LG

Hartmut

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

FKW9, 2023-08-20:
Folgende Test-Daten sind valide für die Smartmeter Kaifa MA309M und Sagecom T210-D **für Netz Niederösterreich**
KEY: `825DC0D167DEEB63F49DAB4F31A86CC7`
DATA: `68FAFA6853FF000167DB084B464D675000088181F82000006005C1FA38BCC6D9594E5A7C3659138B7EE99A8347BF50B998F8338581084512A3780CACBF5BCB366744C99E99E53A12E867D4EDE68EF82A91F6D76C086C73AD5754CE8F1313D9F738C850D49362750A9B6FCBE33ADE62A16C62A9B5CAC79331E9786281604BC92422A124E0C3B9C979D0E265DA601403C556B8960944C424BAD49D63ADABFBAEDA075D66882F5CB55A7AAD43FC24470F3B23BD6BBBFF71C6447A3DEB2EA47D8060D7AAF62F149C0DD4CF60FDC91C20ED9A6DCCF06DA54DFB9B5F4560DFB5364E0E01056A07364A605F8575F3841D517D07220614CFC7CF98825EE720C51CBC59166814146853FF1101674CC1D217B8D8034CC7515FE02095610D16`

Leider sind die M-Bus Frames auch innerhalb Österreich sehr unterschiedlich, wie z.B. für die Vorarlberger Kraftwerke. Dies wird in meinem Programm nicht erkannt, gibt aber einen branch dazu, siehe: Issue #10 und Branch [vkw-test](https://github.com/FKW9/esp-smartmeter-netznoe/tree/vkw-test).

Arduino Simulator gibt es hier, jedoch habe ich keine Erfahrung damit, kam von @micronano0: https://github.com/FKW9/esp-smartmeter-netznoe/issues/10#issuecomment-1638599180

HWHardsoft, 2023-08-22:
Vielen Dank für die schnelle Hilfe. Beide Testdaten + Codes scheinen bei mir zu funktionieren.

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

Mein Program läuft jetzt auf Featherboards mit ESP32 und RP2040. Getestet habe ich bislang:

- Adafruit Feather HUZZAH32
- Sparkfun ESP32 Thing Plus
- Sparkfun Thing Plus RP2040

Wenn ich es für Boards mit anderen Prozessoen compiliere, bekomme ich immer Probleme mit den MBED Bibliotheken. Deshalb überlege ich, eventuell noch einen anderen Stack für TLS zu verwenden z.B. WolfSSL

Das Programm werde ich die nächsten Tage auf meinen Gihub account  hochladen. Parallel arbeite ich auch noch an einer kleinen Zählerdemo für den gleichen Wing, der dann die Simulation eines Verbrauchszählers via MBUS ermöglicht:

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

HWHardsoft, 2023-08-23:
Nachtrag: Ich habe zwischenzeitlich realisiert, dass es [hier](https://github.com/FKW9/esp-smartmeter-netznoe/issues/8) schon eine Implementierung für Arduino ohne die Verwendung von MBEDTLS gibt. In diesem Beispiel wird ausschließlich die Crypto Library für Arduino verwendet. Habe ich mittlerweile auch so in meinem Programm übernommen und funktioniert super. Dadurch ist der Code jetzt auch für andere Prozessoren bzw. Featherboards kompatibel. Erfolgreich getest wurde jetzt:

Adafruit Feather HUZZAH32
Sparkfun ESP32 Thing Plus
Sparkfun Thing Plus RP2040
Adafruit Feather M0 Express
Adafruit Feather nRF52840 Express
Adafruit Feather HUZZAH ESP8266 (läuft aber sinnlos, da nur eine UART vorhanden)
Arduino MKR WIFI1010

Closed 2023-08-23.

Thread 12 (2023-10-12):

VKW Honeywell DM515 Smartmeter _cos phi nicht Korrekt

Soundrico, 2023-10-12:
änderungen im Code (issue 7)
dennoch anzeige de cosphi 0,000 bzw sporadisch 1,983
Ideen?

FKW9, 2023-10-12:
Also wenn die M-Bus Daten korrekt empfangen werden und wirklich nur der Wert hin und her springt geh ich mal davon aus das Honeywell vielleicht einen anderen Datentypen verwendet? Kannst du ein rohes, dekodiertes M-Bus Frame schicken?
Also `DEBUG_OUTPUT` Flag auf true dann sollte es geprintet werden

Soundrico, 2023-10-13:
VOILA:

Encoded raw data stream:
68FAFA6853FF000167DB08454C5310207BB88C8201552100013F8240E27DD024F1BC9BA9CA232CC68C33EDB2A646733C3508B87A8F1CAE7339F52F35673DD1AD2FF798C133E0264F16AAC9D500C1F1DA2A879D7567DDED18D6AE971FFF4841F5D75BEFB2BEEA365461140880D966CC7661B16816A3689F0FA420BF690390B98BF53381EA418C07D79FD74C4F8BC2DE42396A42EECDA55198D1E2C66182874AD3338465AE44F8C946CD4BFD0C2B480A11EA8F498474F7087DFB72BD4C72515A3C9E7423E034FA82209E8E20E7B05276B8E5A081CE8967564637A7FCF1D61F00C0859EEC5C299B2D4CA2AEEBFD7AD140760BF85FB5C3F12C3E25E90D325FD127166872726853FF11016737C91A3FBB2F4E38DC0A149F5FE67861FDB0DC971269C3D9861BC80C42DA3943CBE6589A3138EEA66512C2DB197A96BCA6940BC673AFDFBB76B855D0A7FB06F34499DFED8F2E6A4E0D6FA890E2B0BBE6981BCF2CFE6005CC191C108EB66E990556ED10A68BD4CD37E6902EF72F7A1600
Found OBIS code: 0000010000FF
Unix Time 1697183550
Timestamp 13.10.2023 09:52:30 UTC +02:00
Found OBIS code: 0000600100FF
Found OBIS code: 00002A0000FF
Found OBIS code: 0100200700FF
VoltageL1 229.60
Found OBIS code: 0100340700FF
VoltageL2 230.70
Found OBIS code: 0100480700FF
VoltageL3 231.40
Found OBIS code: 01001F0700FF
CurrentL1 0.61
Found OBIS code: 0100330700FF
CurrentL2 0.93
Found OBIS code: 0100470700FF
CurrentL3 0.23
Found OBIS code: 0100010700FF
ActivePowerPlus 212.00
Found OBIS code: 0100020700FF
ActivePowerMinus 0.00
Found OBIS code: 0100010800FF
ActiveEnergyPlus 320604.00
Found OBIS code: 0100020800FF
ActiveEnergyMinus 0.00
Found OBIS code: 0100030800FF
ReactivePowerPlus 743.00
Found OBIS code: 0100040800FF
ReactivePowerMinus 84075.00
Received valid data!

FKW9, 2023-10-13:
Sry, falscher Branch... Füge bitte nach Zeile 183 in main.cpp das hinzu:
```
#ifdef DEBUG_OUTPUT
        for (int i = 0; i < payload_length; i++)
        {
            Serial.printf("%02X", plaintext[i]);
        }
#endif
````

Aber in dem was du geschickt hast, empfängt er garkeinen Leistungsfaktor (Obis Code 1.0.13.7.0.255 bzw. 01000D0700FF).
Was meinst du dann mit "sporadisch" ?

FKW9, 2023-10-13:
Es könnte aber sogar sein, dass wie im Falle bei Issue #10 (auch VKW) dein Netzbetreiber/Smartmeter gar keinen Leistungsfaktor sendet.

Soundrico, 2023-10-15:
hallo nochmal
anbei der neue print:

Encoded raw data stream:
68FAFA6853FF000167DB08454C5310207BB88C820155210001CFF96B55328F368631AFE9CC68CD1A2F02CA1FFF57460AA05A57EAC81F047B29CDB71C5294D024ED81218B17EFF4C81105DE949D6282D8067402132262DABB7548E3EAE88FBF8C5939310380415B16A296A2DC18A804E73E98D9A12729901B0568F1801E2A4B8E6B4146C94AFB2F2563D725493808509043960F06EEE984899F4FEE5E1A1F8D5EFD42A45FD909307C5028DE365C3E7642D12F03F9FB2043F4E6395607D811A46A6914CA336C743A16308ECD9AEB2564CDDACBE680649FE9971E49303ED4600094D6411E12D46511CEE52D7866DF5772583622F38088D939717B5CC5E1A47158166872726853FF1101672AF72ECB3AFC17A6DB5E767729D1835065DE5A1630AB67F01A17B9304F7A96EEE7AAF4CCCBA23F16763B8689F71C6E44127336DB9D1A70EE0042F73990351B06E26A692F9DA551CEDD15FCE7296DAD954656A73D7235AC243DDC88D1FF86BD29EFE76547D4E7DFE13728800DB718161D
0F0001CB650C07E70A0F070D0E1900FF8880021009060000010000FF090C07E70A0F070D0E1900FF8880020209060000600100FF090E31454C53303230383130383137320202090600002A0000FF0910454C5331323030323038313038313732020309060100200700FF1208F502020FFF1623020309060100340700FF12090102020FFF1623020309060100480700FF12090002020FFF16230203090601001F0700FF12003B02020FFE1621020309060100330700FF12006502020FFE1621020309060100470700FF12001702020FFE1621020309060100010700FF06000000E602020F00161B020309060100020700FF060000000002020F00161B020309060100010800FF060005692D02020F00161E020309060100020800FF060000000002020F00161E020309060100030800FF060000036502020F001620020309060100040800FF0600016CCE02020F001620Found OBIS code: 0000010000FF
Unix Time 1697368465
Timestamp 15.10.2023 13:14:25 UTC +02:00
Found OBIS code: 0000600100FF
Found OBIS code: 00002A0000FF
Found OBIS code: 0100200700FF
VoltageL1 229.30
Found OBIS code: 0100340700FF
VoltageL2 230.50
Found OBIS code: 0100480700FF
VoltageL3 230.40
Found OBIS code: 01001F0700FF
CurrentL1 0.59
Found OBIS code: 0100330700FF
CurrentL2 1.01
Found OBIS code: 0100470700FF
CurrentL3 0.23
Found OBIS code: 0100010700FF
ActivePowerPlus 230.00
Found OBIS code: 0100020700FF
ActivePowerMinus 0.00
Found OBIS code: 0100010800FF
ActiveEnergyPlus 354605.00
Found OBIS code: 0100020800FF
ActiveEnergyMinus 0.00
Found OBIS code: 0100030800FF
ReactivePowerPlus 869.00
Found OBIS code: 0100040800FF
ReactivePowerMinus 93390.00
Received valid data!

Soundrico, 2023-10-17:
Ok, werde mal bei der vkw nachfragen

Von meinem iPhone gesendet

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

FKW9, 2023-10-18:
Alles klar, danke für die info!

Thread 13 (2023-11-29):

MQTT statt Graphite zum senden der Daten?

Soundrico, 2023-11-29:
Hallo Florian,
seit geraumer Zeit versuche ich die Daten in eine Influxdb2 Datenbank zu bekommen - leider erfolglos.
ich versuchte den Code so abzuändern, dass die Daten per MQTT gesendet werden - leider auch erfolglos.
Hast du einen Ansatz wie ich die "Graphite"-Daten in influxdb2 auslesen kann?
In Telegraf habe ich ein Inputplugin configuriert - dieses leider auch nicht funktioniert.
Wäre es keine gute idee die Daten optional in MQTT zu senden?
LG
Soundrico

Soundrico, 2023-11-29:
dsnke für die schnelle Antwort, werde mir das nochmal ansehen
LG aus Vorarlberg

FKW9, 2023-11-29:
Auslesen der Daten von Graphite ist über die Graphite HTTP API möglich (einfach googlen)

Soundrico, 2023-11-29:
danke für den link
wie ich das sehe brächte ich dann aber einen graphiteserver
probier ma etwas aus und melde mich dann -
LG

FKW9, 2023-11-29:
Ok nein dafür extra eine Graphite DB aufzusetzen ist unnötig, dachte du hast schok eine.

Soundrico, 2023-11-29:
ich versuche es in telegraf über einen exec inpusplugin , komm aber nicht mit den conf und templates variablen klar.

Soundrico, 2023-11-29:
wie sendet der esp32 die graphitedaten? smartmeter.voltage.L1 zb
es wäre ja eigendlich ein jsonstring, oder?
im "inputs.exec" inputplugin müsste ich dann in die Templates "die Platzhalter" eintragen.
Ich verstehs leider nicht
lg

FKW9, 2023-11-29:
Graphite (bzw. das Backend: Carbon) erhält die daten in dieser simplen Form über ein einfaches htttp packet `"<metric.path.name> <value> <timestamp od. -1>\n" ` (also nix JSON)

Kenn mich mit Telegraf nicht aus, aber vielleicht helfen dir diese Links:
- https://www.reddit.com/r/influxdb/s/jtGexGpylE
- https://docs.influxdata.com/telegraf/v1/data_formats/input/graphite/

Soundrico, 2023-11-29:
nochmals ein Dankeschön für die beiden links - die Seiten dazu habe ich bereits mehrmals durch
aber ich werde es nochmal mit dem http listener plugin probieren
LG

Soundrico, 2023-12-02:
Hallo Florian
Nach unzähligen Stunden habe ich ein funktionierendes Werk.
Ich Habe den Ansatz mittels Telegraf verworfen und es mit nodered versucht. Da InfluxDB und nodered auf Docker laufen hab dies auch nicht funktioniert bis ich die interne Doktor Ports von docker mit den Host Ports verknüpft habe. Jetzt läuft alles so wie es soll.

Lg aus Vorarlberg

Closed 2023-12-02.

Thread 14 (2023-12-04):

Anpassung an TiNetz

DaPeace, 2023-12-04:
Hallo,
Ich würde deinen Code gerne für meinen TiNetz-Anschluß verwenden.
Ich hab jetzt deinen Code mal für mich angepasst und um MQTT erweitert. Es wird der selbe Kaifa-SM verwendet aber dadurch das sich die Provider-Kennung unterscheidet komme ich da irgendwie nicht weiter.
Ich komme immer bei "Serial.println("Packet was decrypted but data is invalid!");" raus.
Ich hab hier ein Python-Script am laufen bei dem man den Provider einstellen muß.
So schaut da im Script der Code aus:
class Supplier:
    name = None
    frame1_start_bytes_hex = '68fafa68'
    frame1_start_bytes = b'\x68\xfa\xfa\x68'  # 68 FA FA 68
    frame2_end_bytes = b'\x16'
    ic_start_byte = None
    enc_data_start_byte = None

class SupplierTINETZ(Supplier):
    name = "TINETZ"
    frame2_start_bytes_hex = '68727268'
    frame2_start_bytes = b'\x68\x72\x72\x68'  # 68 72 72 68
    ic_start_byte = 23
    enc_data_start_byte = 27

class SupplierEVN(Supplier):
    name = "EVN"
    frame2_start_bytes_hex = '68141468'
    frame2_start_bytes = b'\x68\x14\x14\x68'  # 68 14 14 68
    ic_start_byte = 22
    enc_data_start_byte = 26

Kannst du mir sagen wo ich das anpassen kann bei deinem Code?
Grüsse und Danke schonmal!!

FKW9, 2023-12-08:
in [dlms.h](https://github.com/FKW9/esp-smartmeter-netznoe/blob/master/src/dlms.h):
- `DLMS_HEADER1_LENGTH` auf 27
- `DLMS_IC_OFFSET` auf 23

Dann wird die paylaod-length denke ich auch nicht passen...
[https://github.com/FKW9/esp-smartmeter-netznoe/blob/72f538406e99a903e9722aa38984d9a9b3a05c15/src/main.cpp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](https://github.com/FKW9/esp-smartmeter-netznoe/blob/72f538406e99a903e9722aa38984d9a9b3a05c15/src/main.cpp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)
[](url)

Kannst du mal die rohen, kodierten Daten schicken?

DaPeace, 2023-12-09:
Hallo FKW, danke schonmal für die Antwort.
[cutout_Tinetz.log](https://github.com/FKW9/esp-smartmeter-netznoe/files/13623295/cutout_Tinetz.log)
[received.log](https://github.com/FKW9/esp-smartmeter-netznoe/files/13623296/received.log)
Anbei mal das was ich über den PC mitgeschnitten habe. cutout_Tinetz müsste eigentlich das sein was einen Block darstellt wenn ich nicht völlig daneben liege. Grüsse, Jan

FKW9, 2023-12-09:
Dein Datenpaket:
`68FAFA6853FF000167DB084B464D102007051C82015521004347DA9F0408B31EA33C015E5895BA018A54DC386E78E24E29EABD90925C29278A410A550E9C9DE44CD97DAA76E28053BDF90B462369D8EC5A13F06A9618F8BAA95F4B0AC1ACC2F8444F683C64F1D17D0538E309FF7394EAB298A7A8D732884751054831EA24B78F6B30FF120C761405BB26665DFEA59CFD2DEA667B5E46C74680C8C26824CB0988EBB8A3161AF2FDA33999E8AD25E4165C1A15A0F985D11FD767CF766769564AD02CB42E8213E47AFBDEA7578D781B118AF30CD04D3C9B7AF8EA4107AE991C029662279F88489A13912588A1A2CA645B026745C5FE2340BCEF932512A988BB42166872726853FF110167CC1322628FA905C0F12D51F03A3CFC1AA748EDA14F3C740F384A3AAA6BBABB26E56458E5CDE3B45F8C07635D5578870C7E29FD51850AB3219A903EB1B39B6BAC3133988B796BE6EB75005F7637C31D3F6A5FAF721067DE3E4DE354DC75A1C94DF97E5D7D1857F0E6D413B8EB856916`

Passt auch mit dem Format von VKW überein (siehe #10 oder Branch [vkw-test](https://github.com/FKW9/esp-smartmeter-netznoe/tree/vkw-test))

Ändere mal folgende Variablen auf den Wert:
[https://github.com/FKW9/esp-smartmeter-netznoe/blob/b2c20f459761682da1d9b9684755af54f8c2330c/src/main.cpp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](https://github.com/FKW9/esp-smartmeter-netznoe/blob/b2c20f459761682da1d9b9684755af54f8c2330c/src/main.cpp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)

DaPeace, 2023-12-09:
Ich hab das jetzt mal genau so angepasst. Jetzt bekomme ich
"Unsupported OBIS medium" was immerhin schonmal viel mehr ist als das was ich vorher hatte. Kannst du mir evt. sagen was da noch nicht passt?

FKW9, 2023-12-09:
Der Code vom Branch [vkw-test](https://github.com/FKW9/esp-smartmeter-netznoe/tree/vkw-test) sollte dies lösen. Vergleich beide und implementier die fehlenden Teile!

DaPeace, 2023-12-09:
Super Sache! Funktioniert mit dem Kaifa-Smartmeter mit dem vkw-branch sofort. Direkt noch um MQTT erweitert und schon läuft es Autonom ohne extra Rechner. Fettes Dankeschön von mir !

Closed 2023-12-09.

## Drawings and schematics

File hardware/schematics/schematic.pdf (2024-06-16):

U3

R2

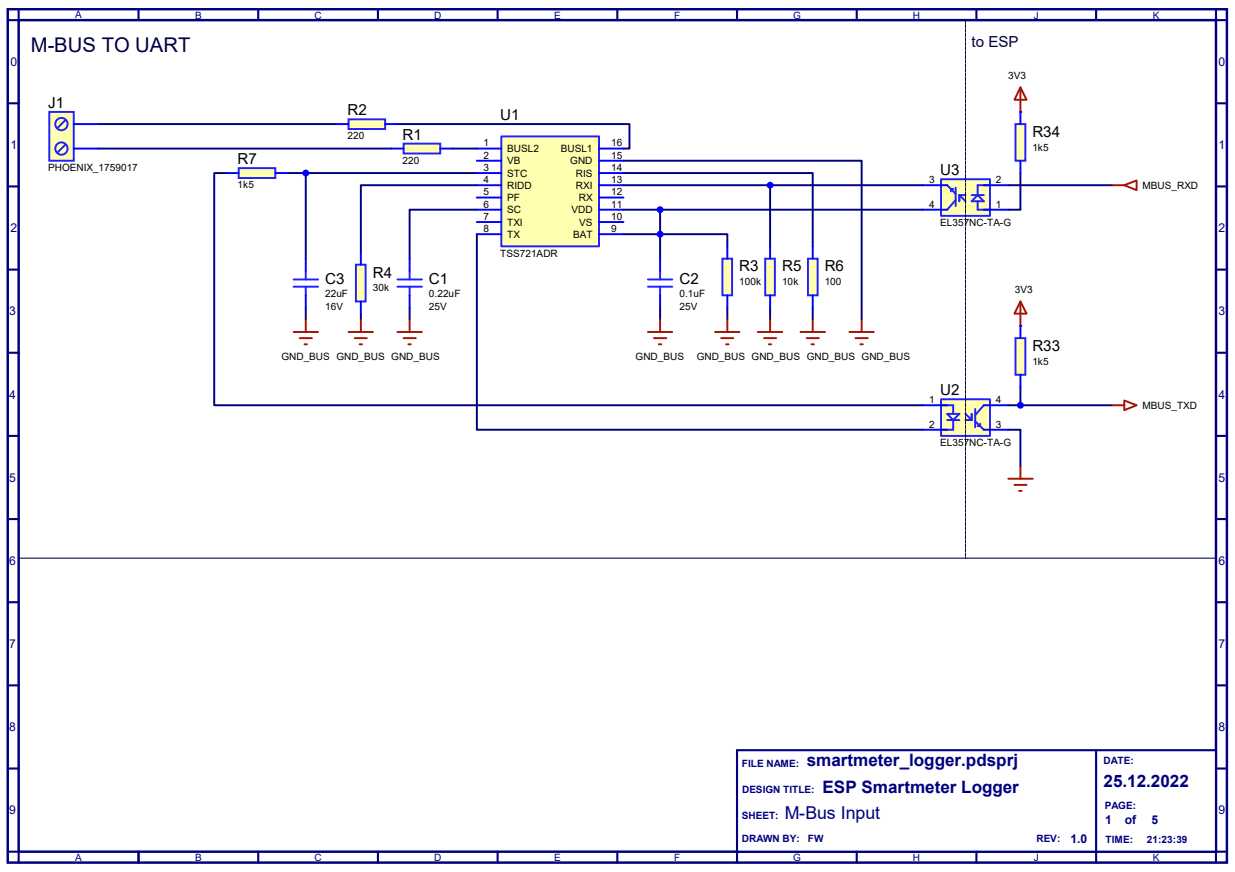
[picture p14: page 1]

FILE NAME:
DESIGN TITLE: ESP Smartmeter Logger
M-Bus Input

FB1
J2

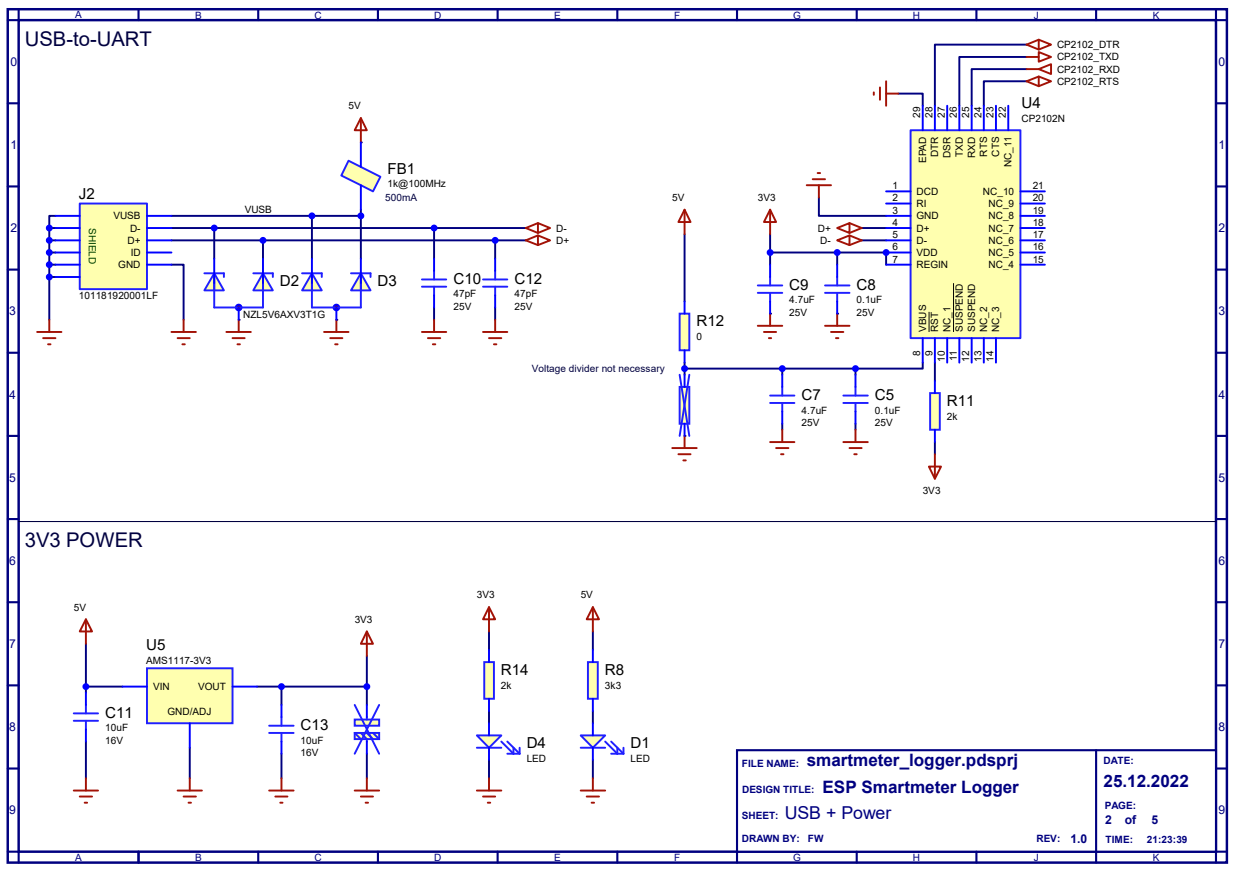
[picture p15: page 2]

Voltage divider not necessary

FILE NAME:
DESIGN TITLE: ESP Smartmeter Logger
USB + Power

C15

# 3V3 3V3 3V³

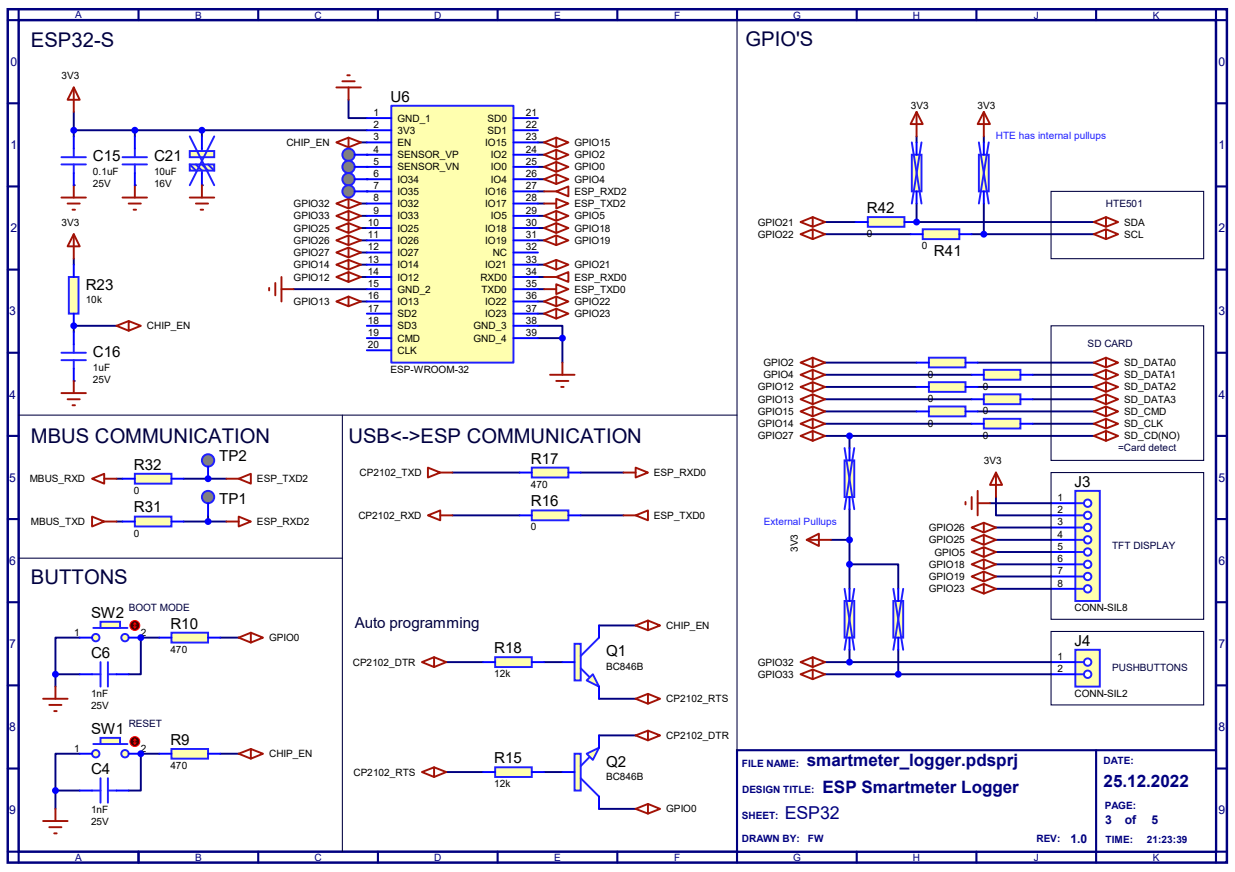
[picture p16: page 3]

HTE has internal pullups

FILE NAME:
DESIGN TITLE: ESP Smartmeter Logger
ESP32

J5

R30

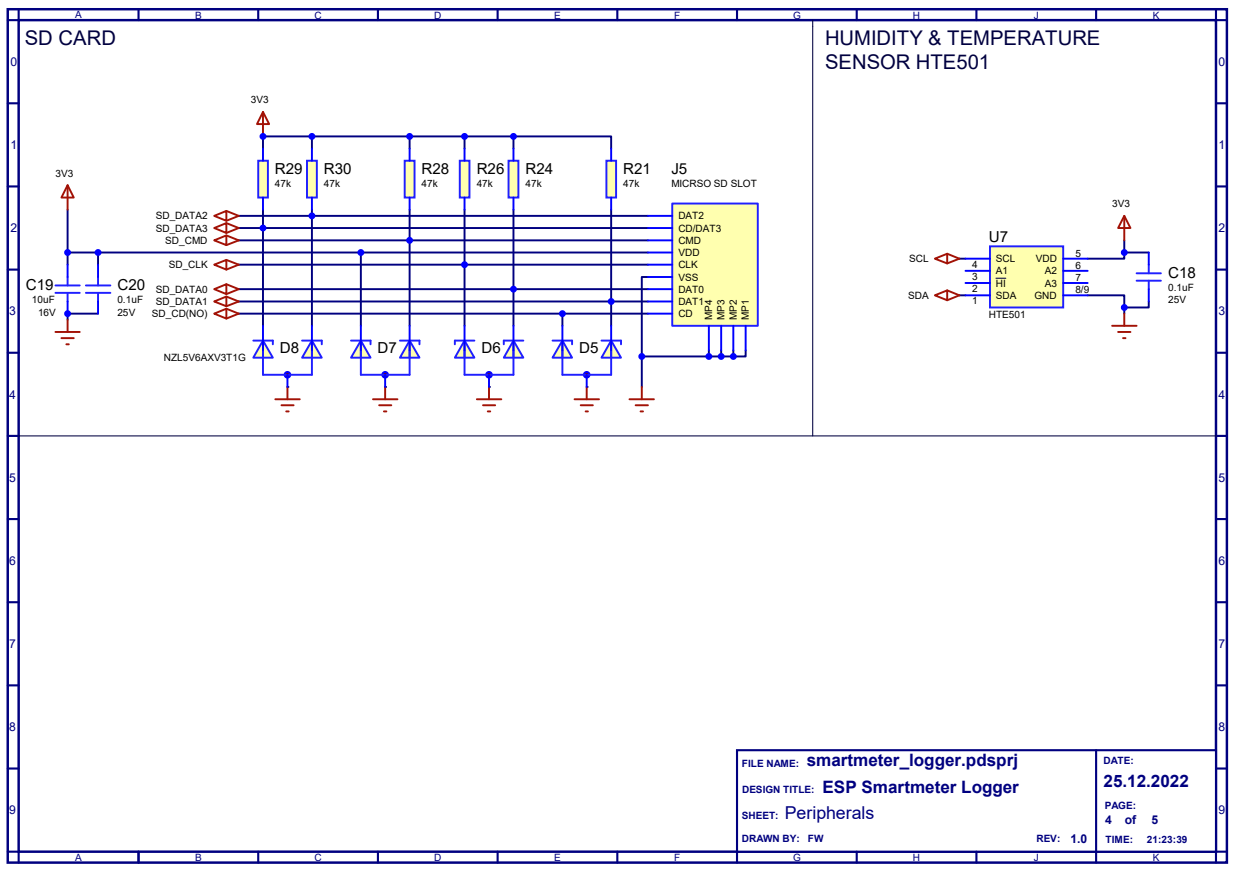
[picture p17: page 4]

FILE NAME:
DESIGN TITLE: ESP Smartmeter Logger
Peripherals

SW1

C2

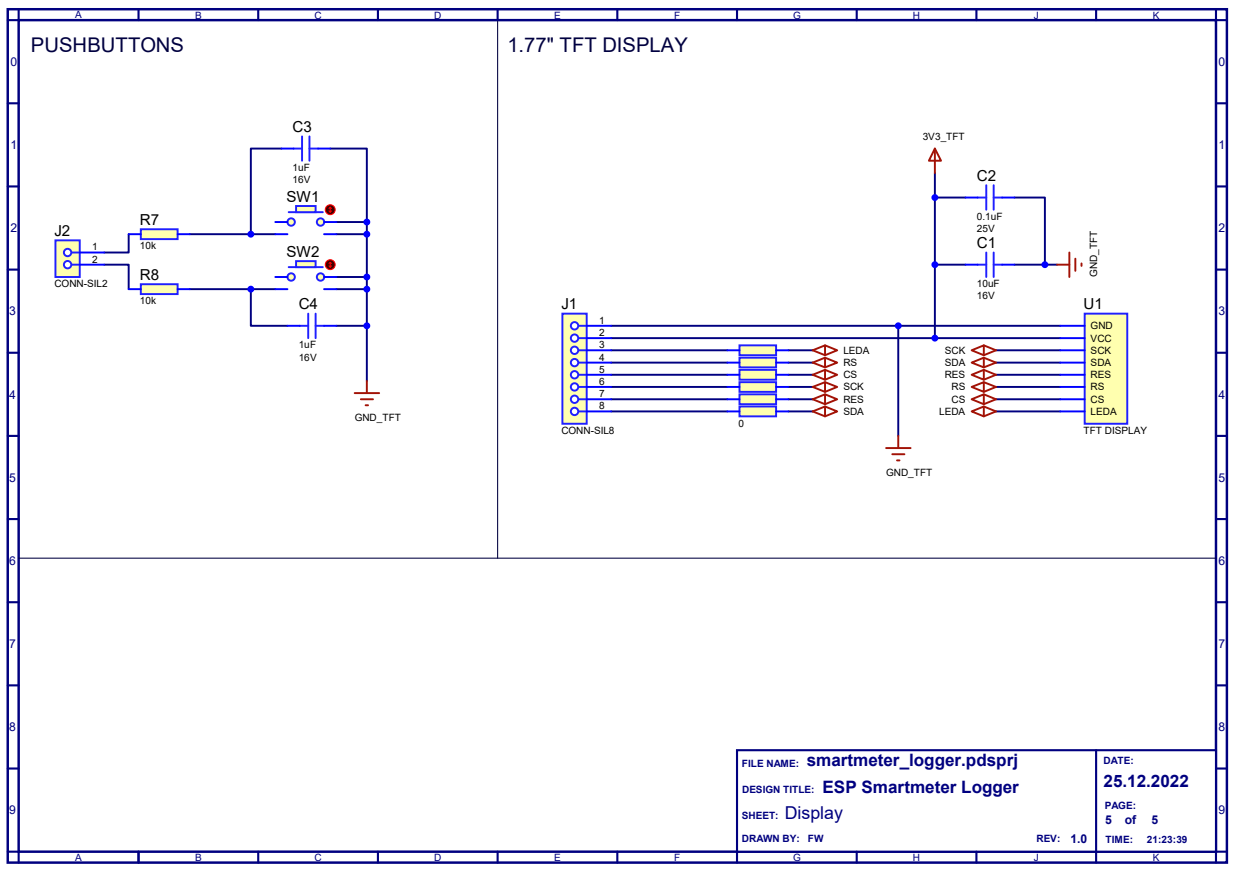
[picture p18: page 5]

FILE NAME:
DESIGN TITLE: ESP Smartmeter Logger
Display

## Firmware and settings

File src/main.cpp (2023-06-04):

#include <Arduino.h>
#include <mbedtls/gcm.h>
#include "dlms.h"
#include "obis.h"
#include "display.h"
#include "hte501.h"
#include "ESPLogger.h"
#include "setup.h"
#include "../key.h"
#include "time.h"

#ifdef USE_GRAPHITE
#include "graphite.h"
#endif

#ifdef TEST_SETUP
#include <random>
#endif

// Variables for DLMS decoding
uint32_t last_read = 0;                      // Timestamp when data was last read
uint16_t receive_buffer_index = 0;           // Current position in the receive buffer
uint8_t receive_buffer[RECEIVE_BUFFER_SIZE]; // Stores the received data
mbedtls_gcm_context aes;

// Variables for RHT sensor
float temperature = 0, humidity = 0;
uint8_t rht_ready = 0;

const char *ntpServer = "at.pool.ntp.org";
unsigned long epochTime;

// Variables for Logging
#ifdef SD_CARD_LOGGING
#include "fileserver.h"
#include "sdcard.h"
uint8_t sd_available = 0;
#endif

// Function prototypes
uint32_t swap_uint32(uint32_t val);
uint16_t swap_uint16(uint16_t val);
void serial_dump();
unsigned long getTime();

// SETUP
void setup()
{
    displaySetup();
    setupSensor();
    startPeriodicMeasurement();

    // Debug port
    Serial.begin(115200);

    // MBus input
    Serial2.begin(2400, SERIAL_8E1);
    Serial2.setRxBufferSize(RECEIVE_BUFFER_SIZE);
    Serial2.setTimeout(2);

    setupWiFi();
    configTime(0, 0, ntpServer);
#ifdef SD_CARD_LOGGING
    sd_available = setupSDCard();
    displaySDCardStatus();
    setupFileserver();
#endif
    etft.printf("\nWarte auf Smartmeter Daten...");
    delay(2000);
}

// MAIN LOOP
void loop()
{
    checkWiFiConnection();
    displayInactiveTimer();
    displayUpdate();

    if (config_update)
    {
        config_update = false;
// blocking
#ifdef SD_CARD_LOGGING
        stopFileserver();
        startConfigAP(true);
        setupFileserver();
#else
        startConfigAP(true);
#endif
    }

    uint32_t current_time = millis();

    if (Serial.available())
    {
        char c = Serial.read();
        if (c == 'd')
            serial_dump();
        if (c == 'r')
            ESP.restart();
    }

    // Read while data is available
    while (Serial2.available())
    {
        if (receive_buffer_index >= RECEIVE_BUFFER_SIZE)
        {
            Serial.println("Buffer overflow!");
            receive_buffer_index = 0;
            return;
        }

        receive_buffer[receive_buffer_index++] = Serial2.read();

        last_read = current_time;
    }

#ifdef TEST_SETUP
    const uint8_t test_data[] = {0x68, 0xFA, 0xFA, 0x68, 0x53, 0xFF, 0x00, 0x01, 0x67, 0xDB, 0x08, 0x4B, 0x46, 0x4D, 0x67, 0x50, 0x00, 0x08, 0x81, 0x81, 0xF8, 0x20, 0x00, 0x00, 0x60, 0x05, 0xC1, 0xFA, 0x38, 0xBC, 0xC6, 0xD9, 0x59, 0x4E, 0x5A, 0x7C, 0x36, 0x59, 0x13, 0x8B, 0x7E, 0xE9, 0x9A, 0x83, 0x47, 0xBF, 0x50, 0xB9, 0x98, 0xF8, 0x33, 0x85, 0x81, 0x08, 0x45, 0x12, 0xA3, 0x78, 0x0C, 0xAC, 0xBF, 0x5B, 0xCB, 0x36, 0x67, 0x44, 0xC9, 0x9E, 0x99, 0xE5, 0x3A, 0x12, 0xE8, 0x67, 0xD4, 0xED, 0xE6, 0x8E, 0xF8, 0x2A, 0x91, 0xF6, 0xD7, 0x6C, 0x08, 0x6C, 0x73, 0xAD, 0x57, 0x54, 0xCE, 0x8F, 0x13, 0x13, 0xD9, 0xF7, 0x38, 0xC8, 0x50, 0xD4, 0x93, 0x62, 0x75, 0x0A, 0x9B, 0x6F, 0xCB, 0xE3, 0x3A, 0xDE, 0x62, 0xA1, 0x6C, 0x62, 0xA9, 0xB5, 0xCA, 0xC7, 0x93, 0x31, 0xE9, 0x78, 0x62, 0x81, 0x60, 0x4B, 0xC9, 0x24, 0x22, 0xA1, 0x24, 0xE0, 0xC3, 0xB9, 0xC9, 0x79, 0xD0, 0xE2, 0x65, 0xDA, 0x60, 0x14, 0x03, 0xC5, 0x56, 0xB8, 0x96, 0x09, 0x44, 0xC4, 0x24, 0xBA, 0xD4, 0x9D, 0x63, 0xAD, 0xAB, 0xFB, 0xAE, 0xDA, 0x07, 0x5D, 0x66, 0x88, 0x2F, 0x5C, 0xB5, 0x5A, 0x7A, 0xAD, 0x43, 0xFC, 0x24, 0x47, 0x0F, 0x3B, 0x23, 0xBD, 0x6B, 0xBB, 0xFF, 0x71, 0xC6, 0x44, 0x7A, 0x3D, 0xEB, 0x2E, 0xA4, 0x7D, 0x80, 0x60, 0xD7, 0xAA, 0xF6, 0x2F, 0x14, 0x9C, 0x0D, 0xD4, 0xCF, 0x60, 0xFD, 0xC9, 0x1C, 0x20, 0xED, 0x9A, 0x6D, 0xCC, 0xF0, 0x6D, 0xA5, 0x4D, 0xFB, 0x9B, 0x5F, 0x45, 0x60, 0xDF, 0xB5, 0x36, 0x4E, 0x0E, 0x01, 0x05, 0x6A, 0x07, 0x36, 0x4A, 0x60, 0x5F, 0x85, 0x75, 0xF3, 0x84, 0x1D, 0x51, 0x7D, 0x07, 0x22, 0x06, 0x14, 0xCF, 0xC7, 0xCF, 0x98, 0x82, 0x5E, 0xE7, 0x20, 0xC5, 0x1C, 0xBC, 0x59, 0x16, 0x68, 0x14, 0x14, 0x68, 0x53, 0xFF, 0x11, 0x01, 0x67, 0x4C, 0xC1, 0xD2, 0x17, 0xB8, 0xD8, 0x03, 0x4C, 0xC7, 0x51, 0x5F, 0xE0, 0x20, 0x95, 0x61, 0x0D, 0x16, 0x68, 0xFA, 0xFA, 0x68, 0x53, 0xFF, 0x00, 0x01, 0x67, 0xDB, 0x08, 0x4B, 0x46, 0x4D, 0x67, 0x50, 0x00, 0x08, 0x81, 0x81, 0xF8, 0x20, 0x00, 0x00, 0x60, 0x05, 0xC1, 0xFA, 0x38, 0xBC, 0xC6, 0xD9, 0x59, 0x4E, 0x5A, 0x7C, 0x36, 0x59, 0x13, 0x8B, 0x7E, 0xE9, 0x9A, 0x83, 0x47, 0xBF, 0x50, 0xB9, 0x98, 0xF8, 0x33, 0x85, 0x81, 0x08, 0x45, 0x12, 0xA3, 0x78, 0x0C, 0xAC, 0xBF, 0x5B, 0xCB, 0x36, 0x67, 0x44, 0xC9, 0x9E, 0x99, 0xE5, 0x3A, 0x12, 0xE8, 0x67, 0xD4, 0xED, 0xE6, 0x8E, 0xF8, 0x2A, 0x91, 0xF6, 0xD7, 0x6C, 0x08, 0x6C, 0x73, 0xAD, 0x57, 0x54, 0xCE, 0x8F, 0x13, 0x13, 0xD9, 0xF7, 0x38, 0xC8, 0x50, 0xD4, 0x93, 0x62, 0x75, 0x0A, 0x9B, 0x6F, 0xCB, 0xE3, 0x3A, 0xDE, 0x62, 0xA1, 0x6C, 0x62, 0xA9, 0xB5, 0xCA, 0xC7, 0x93, 0x31, 0xE9, 0x78, 0x62, 0x81, 0x60, 0x4B, 0xC9, 0x24, 0x22, 0xA1, 0x24, 0xE0, 0xC3, 0xB9, 0xC9, 0x79, 0xD0, 0xE2, 0x65, 0xDA, 0x60, 0x14, 0x03, 0xC5, 0x56, 0xB8, 0x96, 0x09, 0x44, 0xC4, 0x24, 0xBA, 0xD4, 0x9D, 0x63, 0xAD, 0xAB, 0xFB, 0xAE, 0xDA, 0x07, 0x5D, 0x66, 0x88, 0x2F, 0x5C, 0xB5, 0x5A, 0x7A, 0xAD, 0x43, 0xFC, 0x24, 0x47, 0x0F, 0x3B, 0x23, 0xBD, 0x6B, 0xBB, 0xFF, 0x71, 0xC6, 0x44, 0x7A, 0x3D, 0xEB, 0x2E, 0xA4, 0x7D, 0x80, 0x60, 0xD7, 0xAA, 0xF6, 0x2F, 0x14, 0x9C, 0x0D, 0xD4, 0xCF, 0x60, 0xFD, 0xC9, 0x1C, 0x20, 0xED, 0x9A, 0x6D, 0xCC, 0xF0, 0x6D, 0xA5, 0x4D, 0xFB, 0x9B, 0x5F, 0x45, 0x60, 0xDF, 0xB5, 0x36, 0x4E, 0x0E, 0x01, 0x05, 0x6A, 0x07, 0x36, 0x4A, 0x60, 0x5F, 0x85, 0x75, 0xF3, 0x84, 0x1D, 0x51, 0x7D, 0x07, 0x22, 0x06, 0x14, 0xCF, 0xC7, 0xCF, 0x98, 0x82, 0x5E, 0xE7, 0x20, 0xC5, 0x1C, 0xBC, 0x59, 0x16, 0x68, 0x14, 0x14, 0x68, 0x53, 0xFF, 0x11, 0x01, 0x67, 0x4C, 0xC1, 0xD2, 0x17, 0xB8, 0xD8, 0x03, 0x4C, 0xC7, 0x51, 0x5F, 0xE0, 0x20, 0x95, 0x61, 0x0D, 0x16};
    static unsigned long previous_millis = 0;

    if (millis() - previous_millis > 4000)
    {
        previous_millis = last_read = millis();
        memcpy(&receive_buffer, &test_data, sizeof(test_data));
        receive_buffer_index = sizeof(test_data) - 1;
    }
#endif

    if (receive_buffer_index > 0 && current_time - last_read > READ_TIMEOUT)
    {
        if (receive_buffer_index < 256)
        {
            Serial.println("Received packet with invalid size!");
            receive_buffer_index = 0;
            return;
        }

#ifdef DEBUG_OUTPUT
        for (int i = 0; i < 256; i++)
        {
            Serial.printf("%02X", receive_buffer[i]);
        }
#endif

        /**
		 * @TODO: ADD ROUTINE TO DETERMINE PAYLOAD LENGTHS AUTOMATICALLY
		 */

        // used as receive time
        epochTime = getTime();

        uint16_t payload_length = 243;
        uint16_t payload_length_msg1 = 228;
        uint16_t payload_length_msg2 = payload_length - payload_length_msg1;

        uint8_t iv[12]; // Initialization vector

        memcpy(&iv[0], &receive_buffer[DLMS_SYST_OFFSET], DLMS_SYST_LENGTH); // Copy system title to IV
        memcpy(&iv[8], &receive_buffer[DLMS_IC_OFFSET], DLMS_IC_LENGTH);     // Copy invocation counter to IV

        uint8_t ciphertext[payload_length];
        memcpy(&ciphertext[0], &receive_buffer[DLMS_HEADER1_LENGTH], payload_length_msg1);
        memcpy(&ciphertext[payload_length_msg1], &receive_buffer[DLMS_HEADER2_OFFSET + DLMS_HEADER2_LENGTH], payload_length_msg2);

        // Start decrypting
        uint8_t plaintext[payload_length];

        mbedtls_gcm_init(&aes);
        mbedtls_gcm_setkey(&aes, MBEDTLS_CIPHER_ID_AES, KEY, KEY_LENGTH * 8);
        mbedtls_gcm_auth_decrypt(&aes, payload_length, iv, sizeof(iv), NULL, 0, NULL, 0, ciphertext, plaintext);
        mbedtls_gcm_free(&aes);

        if (plaintext[0] != 0x0F || plaintext[5] != 0x0C)
        {
            Serial.println("Packet was decrypted but data is invalid!");
            receive_buffer_index = 0;
            return;
        }

#ifdef DEBUG_OUTPUT
        for (int i = 0; i < payload_length; i++)
        {
            Serial.printf("%02X", plaintext[i]);
        }
#endif

        // Decode data
        uint16_t current_position = DECODER_START_OFFSET;
        meterData meter_data;

        // Use epoch time (UTC) as timestamp for the meter data,
        // so that every metric has the same timestamp.
        // With using -1 there is a small time shift, hence post processing
        // will be annoying.
        meter_data.timestamp_unix = epochTime;

        do
        {
            if (plaintext[current_position + OBIS_TYPE_OFFSET] != DATA_OCTET_STRING)
            {
                // For Sagemcom the Meter Number is bugged, so skip the garbage...
                if (current_position >= 229)
                {
                    break;
                }
                else
                {
                    Serial.print("Unsupported OBIS header type!");
                    receive_buffer_index = 0;
                    return;
                }
            }

            uint8_t data_length = plaintext[current_position + OBIS_LENGTH_OFFSET];

            if (data_length != 0x06)
            {
                // read timestamp
                if ((data_length == 0x0C) && (current_position == DECODER_START_OFFSET))
                {
                    uint8_t dateTime[data_length];
                    memcpy(&dateTime[0], &plaintext[current_position + 2], data_length);

                    uint16_t year;
                    uint8_t month, day, hour, minute, second;

                    year = (plaintext[current_position + 2] << 8) + plaintext[current_position + 3];
                    month = plaintext[current_position + 4];
                    day = plaintext[current_position + 5];
                    hour = plaintext[current_position + 7];
                    minute = plaintext[current_position + 8];
                    second = plaintext[current_position + 9];

                    sprintf(meter_data.timestamp_str, "%02u.%02u.%04u %02u:%02u:%02u", day, month, year, hour, minute, second);

                    // meter_data.timestamp_unix = -1;

                    // COMMENTED OUT BECAUSE I DONT WANT THE PAIN CONVERSION WITH TIMEZONZES
                    //
                    // convert to unix timestamp for graphite
                    // struct tm tm;
                    // if (strptime(meter_data.timestamp_str, "%d.%m.%Y %H:%M:%S", &tm) != NULL)
                    // {
                    //// TODO: detect time zone summer time/winter time
                    //     meter_data.timestamp_unix = mktime(&tm) - 7200;
                    //     Serial.print("Unix Time: ");
                    //     Serial.println(meter_data.timestamp_unix);
                    // }
                    // else
                    // {
                    //     Serial.println("Invalid Timestamp");
                    //     receive_buffer_index = 0;
                    //     return;
                    // }

                    Serial.print("Timestamp: ");
                    Serial.println(meter_data.timestamp_str);

                    current_position = 34;
                    data_length = plaintext[current_position + OBIS_LENGTH_OFFSET];
                }
                else if ((data_length == 0x0C) && (current_position > 225))
                {
                    uint8_t meterNumber[data_length];
                    memcpy(&meterNumber[0], &plaintext[current_position + 2], data_length);

                    Serial.print("Meter Number: ");
                    for (int i = 0; i < data_length; i++)
                    {
                        Serial.printf("%02X", meterNumber[i]);
                    }

                    // THIS IS THE END OF THE PACKET
                    break;
                }
                else
                {
                    Serial.println("Unsupported OBIS header length");
                    receive_buffer_index = 0;
                    return;
                }
            }

            uint8_t obis_code[data_length];
            memcpy(&obis_code[0], &plaintext[current_position + OBIS_CODE_OFFSET], data_length); // Copy OBIS code to array

            current_position += data_length + 2; // Advance past code, position and type

            uint8_t obis_data_type = plaintext[current_position];
            current_position++; // Advance past data type

            uint8_t obis_data_length = 0x00;
            uint8_t code_type = TYPE_UNKNOWN;

            if (obis_code[OBIS_A] == 0x01)
            {
                // Compare C and D against code
                if (memcmp(&obis_code[OBIS_C], OBIS_VOLTAGE_L1, 2) == 0)
                {
                    code_type = TYPE_VOLTAGE_L1;
                }
                else if (memcmp(&obis_code[OBIS_C], OBIS_VOLTAGE_L2, 2) == 0)
                {
                    code_type = TYPE_VOLTAGE_L2;
                }
                else if (memcmp(&obis_code[OBIS_C], OBIS_VOLTAGE_L3, 2) == 0)
                {
                    code_type = TYPE_VOLTAGE_L3;
                }

                else if (memcmp(&obis_code[OBIS_C], OBIS_CURRENT_L1, 2) == 0)
                {
                    code_type = TYPE_CURRENT_L1;
                }
                else if (memcmp(&obis_code[OBIS_C], OBIS_CURRENT_L2, 2) == 0)
                {
                    code_type = TYPE_CURRENT_L2;
                }
                else if (memcmp(&obis_code[OBIS_C], OBIS_CURRENT_L3, 2) == 0)
                {
                    code_type = TYPE_CURRENT_L3;
                }

                else if (memcmp(&obis_code[OBIS_C], OBIS_ACTIVE_POWER_PLUS, 2) == 0)
                {
                    code_type = TYPE_ACTIVE_POWER_PLUS;
                }
                else if (memcmp(&obis_code[OBIS_C], OBIS_ACTIVE_POWER_MINUS, 2) == 0)
                {
                    code_type = TYPE_ACTIVE_POWER_MINUS;
                }

                else if (memcmp(&obis_code[OBIS_C], OBIS_ACTIVE_ENERGY_PLUS, 2) == 0)
                {
                    code_type = TYPE_ACTIVE_ENERGY_PLUS;
                }
                else if (memcmp(&obis_code[OBIS_C], OBIS_ACTIVE_ENERGY_MINUS, 2) == 0)
                {
                    code_type = TYPE_ACTIVE_ENERGY_MINUS;
                }

                else if (memcmp(&obis_code[OBIS_C], OBIS_POWER_FACTOR, 2) == 0)
                {
                    code_type = TYPE_POWER_FACTOR;
                }
                else
                {
                    Serial.println("Unsupported OBIS code");
                }
            }
            else
            {
                Serial.println("Unsupported OBIS medium");
                receive_buffer_index = 0;
                return;
            }

            uint16_t uint16_value;
            uint32_t uint32_value;
            float float_value;

            switch (obis_data_type)
            {
            case DATA_LONG_DOUBLE_UNSIGNED:
                obis_data_length = 4;

                memcpy(&uint32_value, &plaintext[current_position], 4); // Copy uint8_ts to integer
                uint32_value = swap_uint32(uint32_value);               // Swap uint8_ts

                float_value = uint32_value; // Ignore decimal digits for now

                switch (code_type)
                {
                case TYPE_ACTIVE_POWER_PLUS:
                    meter_data.power_plus = float_value;
                    Serial.print("ActivePowerPlus ");
                    Serial.println(float_value);
                    break;

                case TYPE_ACTIVE_POWER_MINUS:
                    meter_data.power_minus = float_value;
                    Serial.print("ActivePowerMinus ");
                    Serial.println(float_value);
                    break;

                case TYPE_ACTIVE_ENERGY_PLUS:
                    meter_data.energy_plus = float_value + ACTIVE_ENERGY_PLUS_OFFSET;
                    Serial.print("ActiveEnergyPlus ");
                    Serial.println(float_value);
                    break;

                case TYPE_ACTIVE_ENERGY_MINUS:
                    meter_data.energy_minus = float_value;
                    Serial.print("ActiveEnergyMinus ");
                    Serial.println(float_value);
                    break;
                }
                break;

            case DATA_LONG:
            case DATA_LONG_UNSIGNED:
                obis_data_length = 2;

                memcpy(&uint16_value, &plaintext[current_position], 2); // Copy uint8_ts to integer
                uint16_value = swap_uint16(uint16_value);               // Swap uint8_ts

                if (plaintext[current_position + 5] == SCALE_TENTHS)
                    float_value = uint16_value / 10.0;
                else if (plaintext[current_position + 5] == SCALE_HUNDREDTHS)
                    float_value = uint16_value / 100.0;
                else if (plaintext[current_position + 5] == SCALE_THOUSANDS)
                    float_value = uint16_value / 1000.0;
                else
                    float_value = uint16_value;

                switch (code_type)
                {
                case TYPE_VOLTAGE_L1:
                    meter_data.voltage_l1 = float_value;
                    Serial.print("VoltageL1 ");
                    Serial.println(float_value);
                    break;

                case TYPE_VOLTAGE_L2:
                    meter_data.voltage_l2 = float_value;
                    Serial.print("VoltageL2 ");
                    Serial.println(float_value);
                    break;

                case TYPE_VOLTAGE_L3:
                    meter_data.voltage_l3 = float_value;
                    Serial.print("VoltageL3 ");
                    Serial.println(float_value);
                    break;

                case TYPE_CURRENT_L1:
                    meter_data.current_l1 = float_value;
                    Serial.print("CurrentL1 ");
                    Serial.println(float_value);
                    break;

                case TYPE_CURRENT_L2:
                    meter_data.current_l2 = float_value;
                    Serial.print("CurrentL2 ");
                    Serial.println(float_value);
                    break;

                case TYPE_CURRENT_L3:
                    meter_data.current_l3 = float_value;
                    Serial.print("CurrentL3 ");
                    Serial.println(float_value);
                    break;

                case TYPE_POWER_FACTOR:
                    meter_data.cos_phi = float_value;
                    Serial.print("PowerFactor ");
                    Serial.println(float_value);
                    break;
                }
                break;

            case DATA_OCTET_STRING:
                obis_data_length = plaintext[current_position];
                current_position++; // Advance past string length
                break;

            default:
                Serial.println("Unsupported OBIS data type");
                receive_buffer_index = 0;
                return;
                break;
            }

            current_position += obis_data_length; // Skip data length

            current_position += 2; // Skip pause after data

            if (plaintext[current_position] == 0x0F)  // There is still additional data for this type, skip it
                current_position += 4;                // Skip additional data and additional break; this will jump out of bounds on last frame
        } while (current_position <= payload_length); // Loop until end of packet

        receive_buffer_index = 0;
        Serial.println("Received valid data!");

        meter_data.rssi = WiFi.RSSI();
        // Read RHT sensor
        if (newMeasurementReady(rht_ready))
        {
            if (rht_ready)
            {
                if (fetchPeriodicTemperatureHumidity(temperature, humidity))
                {
                    meter_data.humidity = humidity;
                    meter_data.temperature = temperature;
                }
            }
        }

        // send the data
#ifdef USE_GRAPHITE
        uint32_t start_send_t = millis();
        submitToGraphite(GRAPHITE_CURRENT_L1, meter_data.current_l1, meter_data.timestamp_unix);
        submitToGraphite(GRAPHITE_CURRENT_L2, meter_data.current_l2, meter_data.timestamp_unix);
        submitToGraphite(GRAPHITE_CURRENT_L3, meter_data.current_l3, meter_data.timestamp_unix);
        submitToGraphite(GRAPHITE_ACTIVE_POWER_PLUS, meter_data.power_plus, meter_data.timestamp_unix);
        submitToGraphite(GRAPHITE_ACTIVE_ENERGY_PLUS, meter_data.energy_plus, meter_data.timestamp_unix);
        submitToGraphite(GRAPHITE_POWER_FACTOR, meter_data.cos_phi, meter_data.timestamp_unix);
        submitToGraphite(GRAPHITE_RSSI, meter_data.rssi, meter_data.timestamp_unix);
        submitToGraphite(GRAPHITE_T, meter_data.temperature, meter_data.timestamp_unix);
        submitToGraphite(GRAPHITE_RH, meter_data.humidity, meter_data.timestamp_unix);
        submitToGraphite(GRAPHITE_VOLTAGE_L1, meter_data.voltage_l1, meter_data.timestamp_unix);
        submitToGraphite(GRAPHITE_VOLTAGE_L2, meter_data.voltage_l2, meter_data.timestamp_unix);
        submitToGraphite(GRAPHITE_VOLTAGE_L3, meter_data.voltage_l3, meter_data.timestamp_unix);
        submitToGraphite(GRAPHITE_ACTIVE_POWER_MINUS, meter_data.power_minus, meter_data.timestamp_unix);
        submitToGraphite(GRAPHITE_ACTIVE_ENERGY_MINUS, meter_data.energy_minus, meter_data.timestamp_unix);
        submitToGraphite(GRAPHITE_SEND_TIME, (float)(millis() - start_send_t), meter_data.timestamp_unix);
        submitToGraphite(GRAPHITE_PROC_TIME, (float)(start_send_t - current_time), meter_data.timestamp_unix);
#endif

        // update the display
        displayMeterData(&meter_data);
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

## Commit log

2022-04-01 wifi powersave off
2022-04-08 temporary fix for summer time
    [main.cpp]
2022-08-20 hardware version 1.0
    [BOM.xlsx, enclosure.dwg]
2022-08-20 modified sd card footprint, removed paste layer on testpads
2022-09-02 implemented RHT Sensor
2022-09-19 minor pcb changes
2022-09-19 fix for sagecom power factor
    [main.cpp, obis.h]
2022-11-25 button interrupts, use graphite host timestamp
2022-11-26 added first screen to display current and voltage
2022-11-26 added second screen for power and cos(phi)
2022-12-25 improved function getOldestFile included WiFi Manager and Settings screen moved key to seperate file added more tft screens serial dump function turn off display after 2 minutes inactivity delete old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
2022-12-25 removed GND connection from HTE501 A1,A2,A3 added termal relief at Pin P6 at Micro SD Slot added debouncing filters for both buttons added notch on Display PCB because M-Bus terminal was block
2023-03-16 updated BOM and cost calculations
2023-03-16 removed file
    [BOM.xlsx]
2023-03-16 update BOM and cost
2023-03-16 bom update
2023-04-14 Fixes for Sagemcom T210-D, minor bugfixes, debug stuff
    [AuswertungDLMS_ADPU.xlsx]
2023-06-04 use ntp server for current time include send and process time metric minor changes
